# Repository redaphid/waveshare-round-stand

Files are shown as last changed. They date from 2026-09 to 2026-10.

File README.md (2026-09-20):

# Waveshare round-board desk stands

Minimal angled stands for Waveshare's round ESP32-S3 display boards. One design,
three sizes: a tapered wedge with a groove angled 20° back from vertical, and a
cable notch cut straight through the middle so a USB-C lead runs *through* the
stand rather than over it. The board drops in rim-first — nothing clips, nothing
flexes, no fasteners.

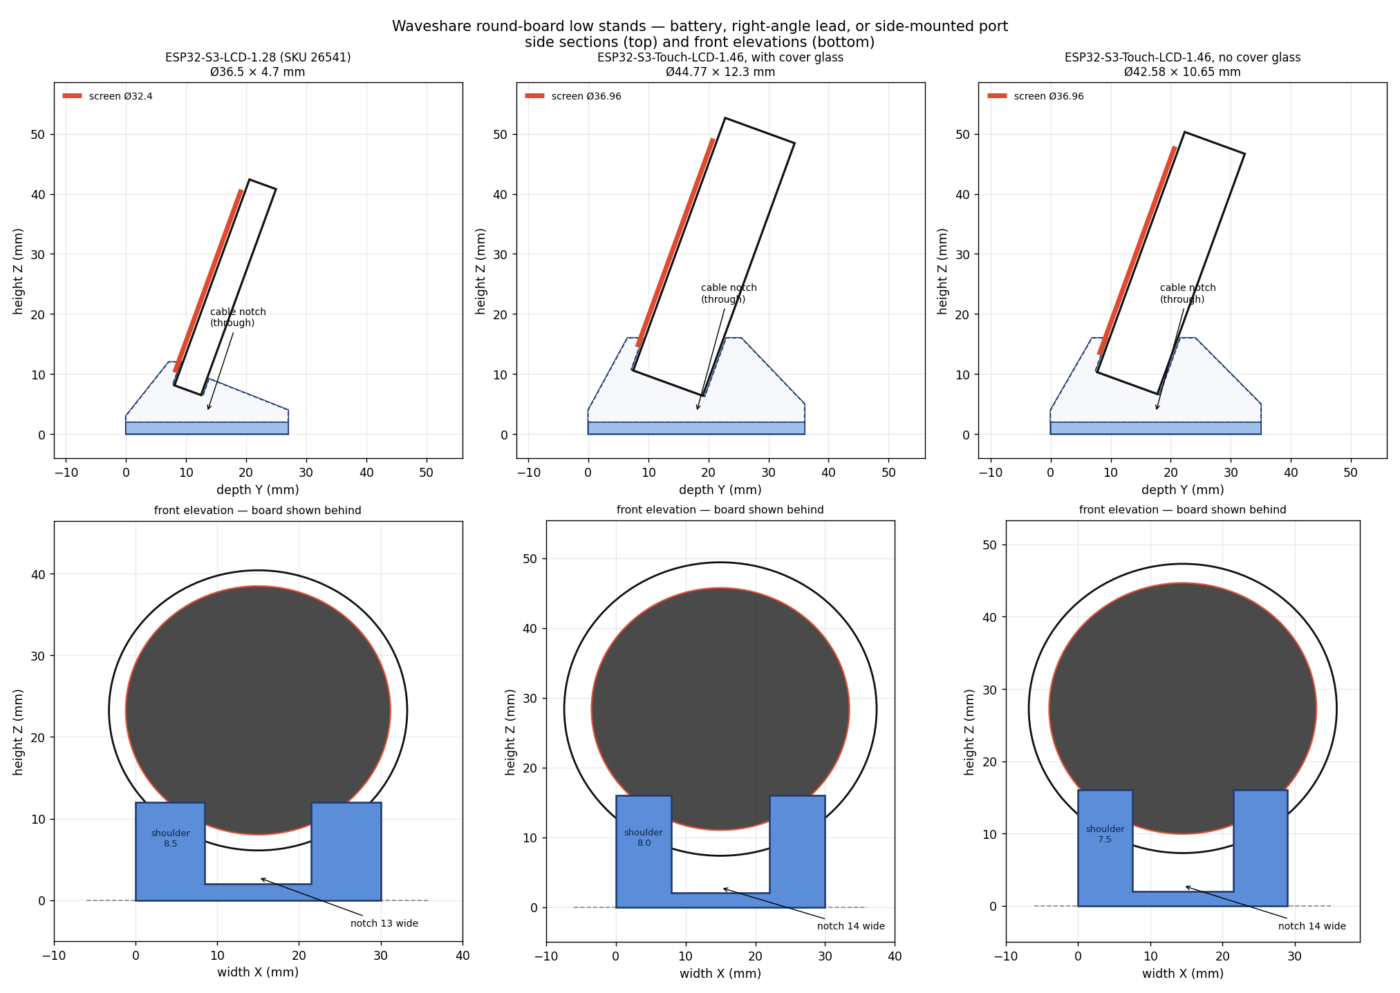
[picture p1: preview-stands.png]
low stands


| board | stand | groove | notch | screen top | material |
|---|---|---|---|---|---|
| ESP32-S3-LCD-1.28 (SKU 26541) | [`stl/small/Stand.stl`](stl/small/Stand.stl) | 5.4 × 5 mm (rear wall 3 mm) | 13 mm | 41.6 mm | 4.6 g |
| ESP32-S3-Touch-LCD-1.46, cover glass | [`stl/large/Stand - cover glass.stl`](<stl/large/Stand - cover glass.stl>) | 13.1 × 8 mm | 14 mm | 50.6 mm | 8.9 g |
| ESP32-S3-Touch-LCD-1.46, bare | [`stl/large/Stand - no cover glass.stl`](<stl/large/Stand - no cover glass.stl>) | 11.5 × 8 mm | 14 mm | 48.5 mm | 8.2 g |

### Docks — for a straight USB-C cable in the bottom port

The low stands leave ~5 mm under the board rim. A straight USB-C plug body is
~20–25 mm, so with the 1.46's bottom port in use the board can't seat — it ends
up lying across the stand. The docks lift the board so the plug hangs straight
down through the notch and the cable turns out the back at desk level.

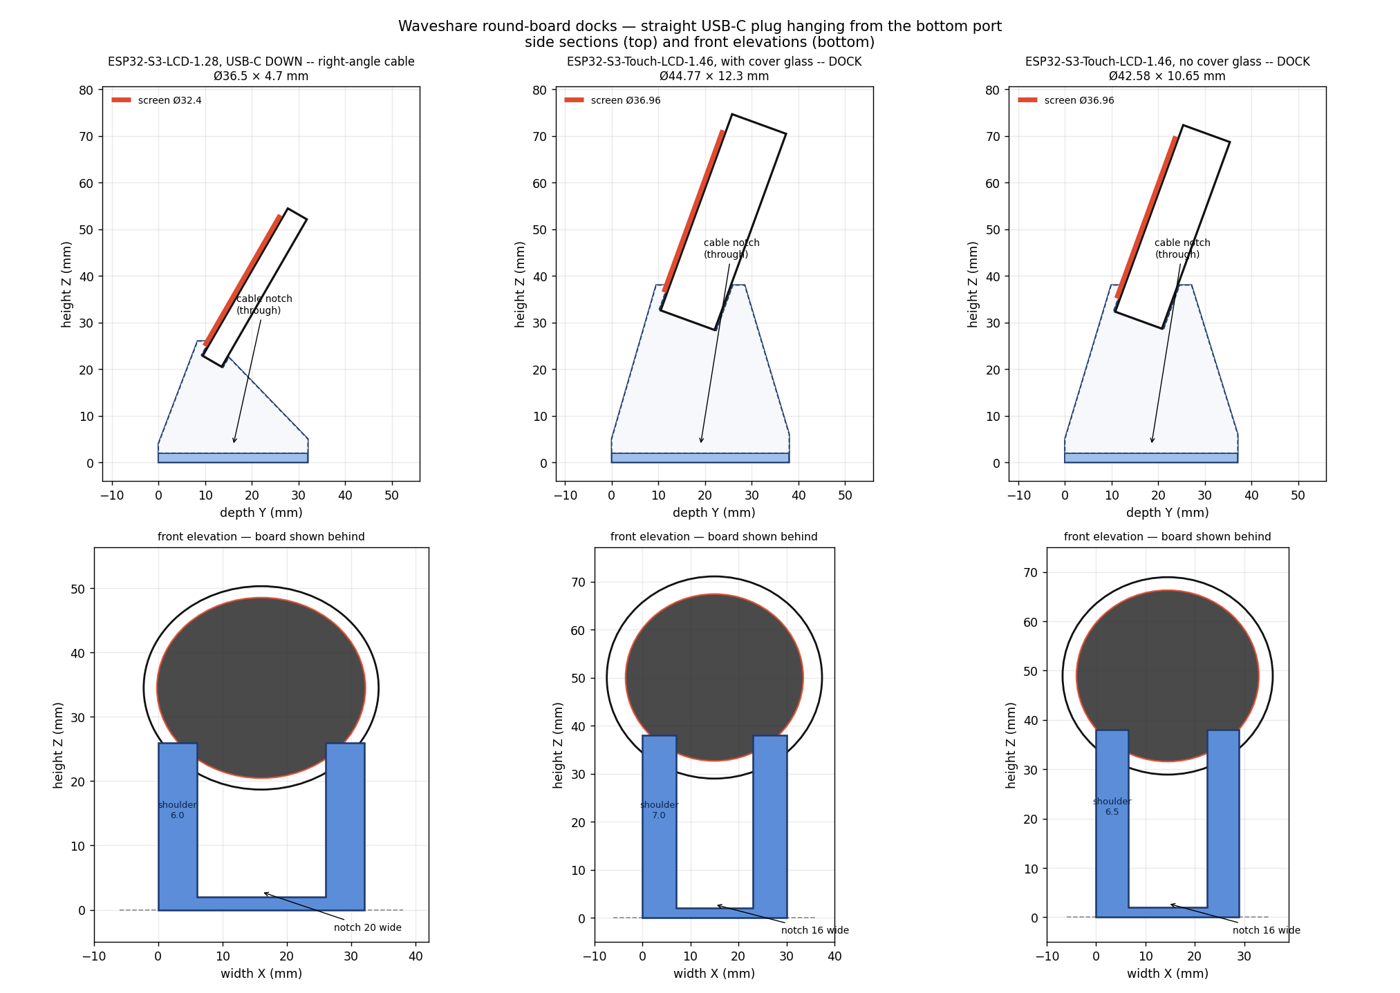
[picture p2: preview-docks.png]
docks


| board | dock | clear under rim | screen top | material |
|---|---|---|---|---|
| ESP32-S3-Touch-LCD-1.46, cover glass | `large/Dock for straight cable - cover glass.stl` | **27.0 mm** | 72.6 mm | 19.8 g |
| ESP32-S3-Touch-LCD-1.46, bare | `large/Dock for straight cable - no cover glass.stl` | **26.9 mm** | 70.5 mm | 17.9 g |
| ESP32-S3-LCD-1.28, **USB-C down** | `small/Dock for right-angle cable - USB-C down.stl` | **14.7 mm** | 51.3 mm | 9.4 g |

The 1.28 one is for an **L-shaped USB-C cable**: the badge goes in **turned
over**, tab down, so the port faces the desk. It leans back **30°** rather than
20 — that points the port down-and-forward, so the plug tucks into the notch
instead of needing headroom under the rim. The notch is **20 mm** to pass the
18.37 mm USB-C tab. The screen ends up upside down: **rotate it in firmware**.

Same groove, same notch (widened to 16 mm for plug bodies), ridge raised from
16 mm to 38 mm and the groove moved 3 mm back. Sized for a 24 mm plug body with
3 mm spare for the cable to turn. Because the board leans back, the plug leans
*forward* as it descends and lands about 6 mm in from the front edge; the notch
is open at both ends, so the cable runs out the front or 32 mm back along the
floor to exit behind. Twice the material of the low stand — the cost of holding
the board 27 mm off the desk.

Print flat on the base. No supports, no overhangs. Masses are PETG.

**1.28 with a button:** `stl/small/Stand - BOOT button.stl` adds a post behind the
badge's BOOT switch so pressing the screen clicks it (RESET twin too). Details
in [`PRINTING.md`](PRINTING.md#the-128-button-post-stands).

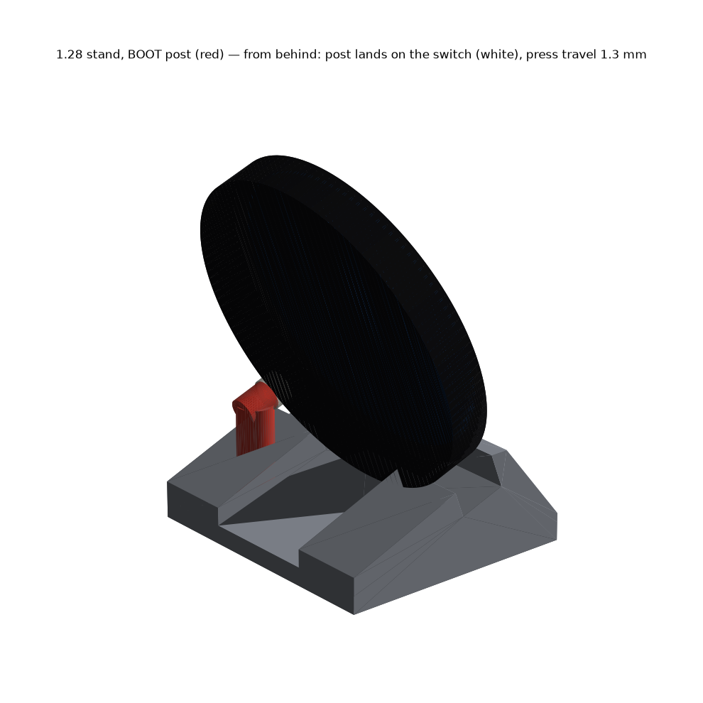
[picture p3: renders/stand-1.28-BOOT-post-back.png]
BOOT post


**Printable files live in [`stl/`](stl/).**

## The pod — where this is heading

The stands were the warm-up. The goal is an **instrument cluster clipped to the
side of a monitor** with the look of a 2G DSM A-pillar gauge pod: cups, trim
rings, gauges canted toward you. That lives in [`pod/`](pod/) — its own README,
STLs, and renders. The stands and docks above stay as they are.

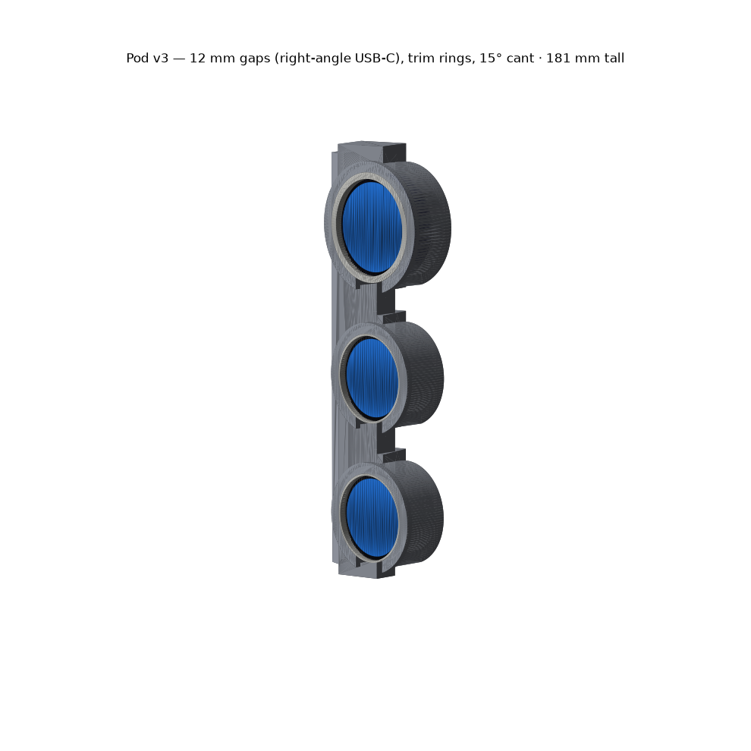
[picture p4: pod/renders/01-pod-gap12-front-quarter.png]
pod


## Start here

- **[`PRINTING.md`](PRINTING.md)** — which file to print, slicer presets, plate
  orientation, how to seat each board, what the notch does and doesn't do.
- **[`BOARDS.md`](BOARDS.md)** — verified dimensions and pin maps for both
  boards, how the two sizes actually compare, and how to tell the two 1.46
  variants apart.
- **[`reference/`](reference/)** — Waveshare's own outline and pinout drawings,
  with source URLs in [`SOURCES.md`](reference/SOURCES.md).

## Three things worth knowing

1. **The 1.46 ships in two cover-glass options and they are different parts** —
   Ø44.77 / 12.30 mm thick with glass, Ø42.58 / 10.65 mm without. The grooves
   differ by 1.65 mm. Check yours before printing; see `BOARDS.md`.
2. **On the low stands the notch is a cable route, not a plug socket.** It
   leaves 4.1–5.4 mm under the board rim — fine for a bare lead or a
   right-angle plug, not a straight plug in the bottom port. **For a straight
   plug, print the dock.** See `PRINTING.md`.
3. **The two boards are closer in size than they look.** The 1.46's PCB is only
   6.1 mm wider than the 1.28's. What differs enormously is thickness — 1.6 mm
   of bare PCB rim versus a 12.3 mm stack.

## Why these aren't from Printables

Nothing there targets these boards. Searches surface models for the
**ESP32-S3-Touch-LCD-1.28** (a different outline from the non-touch 1.28) or for
the bare 1.28-inch LCD module. So these are built from Waveshare's outline
drawings instead — neither product page states its dimensions in text, they
exist only inside a diagram image.

## Design

A straight groove holding a round board is the plate-stand trick: the disc
contacts the groove on two lines and cannot rock. It buys three things over a
cradle or a tripod — no supports needed, no thin snap features to fatigue, and
because the board is round you can rotate it to put the connectors where you
want them.

The solid is three slabs stacked across the width: full wedge, base slab, full
wedge. The two outer slabs carry the groove; the middle one is just the floor,
which is what makes the notch. Because the slabs share their lower boundary
exactly, the exposed face at each internal boundary is one simple polygon, so
the mesh comes out watertight without needing a general polygon boolean.
`check_stl.py` proves that rather than assuming it.

## Files

| file | what it is |
|---|---|
| `build_stands.py` | generates all five STLs from one parameter table; prints a geometry report and asserts the board fits the base, the centre of mass stays centred, the notch floor clears the groove floor, a cable actually fits under the rim, and — for docks — that a straight plug does |
| `build_stand_button.py [BOOT\|RESET]` | the 1.28 stand with a switch post; manifold3d, in the `~/.venvs/cad` venv |
| `build_all.sh` | everything below, plus a docs link-check; run before any commit |
| `check_stl.py <f.stl>` | verifies watertightness, outward normals, no degenerate facets; exits non-zero on a problem |
| `preview.py` → `preview-stands.png`, `preview-docks.png` | side sections and front elevations per family, board drawn in place |
| `stand.scad` | same model, parametric, for tweaking in OpenSCAD; set `variant` at the top |
| `flatten_presets.py` | resolves an ElegooSlicer preset's `inherits` chain into one flat preset — see the automation note in `PRINTING.md` |
| `pod/` | the gauge pod + adjustable monitor clip — see [`pod/README.md`](pod/README.md) |
| `archive/` | superseded files, kept rather than deleted; see `archive/NOTE.md` |

## For whoever works on this next

- **[`CLAUDE.md`](CLAUDE.md)** — the agent brief: what's verified, conventions, how to work here
- **[`docs/DESIGN.md`](docs/DESIGN.md)** — every design decision and what it replaced
- **[`docs/TOOLCHAIN.md`](docs/TOOLCHAIN.md)** — the two pipelines, venv setup, renderer limits, the slicer-CLI post-mortem
- **[`docs/PRINT-LOG.md`](docs/PRINT-LOG.md)** — what has actually been printed
- **`.claude/skills/`** — `rebuild-and-ship`, `add-board`, `measure-drawing`, `after-a-print`, `pod-iterate`
- **`./build_all.sh`** — rebuild, validate, render, link-check, in one go

## Regenerating

```
./build_all.sh
```

Or piecemeal:

```
python3 build_stands.py
for f in stl/*/*.stl; do python3 check_stl.py "$f"; done
python3 preview.py
```

Pure standard library for the STL generator and validator; matplotlib only for
the previews.

## Licence

MIT — see [`LICENSE`](LICENSE).

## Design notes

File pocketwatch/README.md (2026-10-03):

# Pocketwatch case (1.28 badge)

**Ø52.3 × 23.4 mm. Three parts. Sized for the Makerfocus 1000 mAh LiPo (7.4 × 22.28 × 42.65).**

| print | file | orientation | supports |
|---|---|---|---|
| **case** | `stl/pocketwatch/Pocketwatch - case.stl` | bezel face down, as exported | none |
| **plate** | `stl/pocketwatch/Pocketwatch - plate.stl` | flat back down, guides and post up, as exported | none |
| **lid** | `stl/pocketwatch/Pocketwatch - lid.stl` | flat, as exported | none |

## Assembly, in order

1. **Badge** into the case from the back, screen first, USB-C tab into the slot at 12 o'clock.
2. **Battery plug** through the square hole in the plate, then into the badge's JST.
3. **Plate** onto the step behind the badge, header sockets into the two guides. Press until it snaps.
4. **Battery** into the chamber, wire end toward 12 o'clock, wire laid in the channel on the plate.
5. **Lid** pressed in until it snaps.
6. Any straight USB-C cable into the recess at 12 o'clock. The cable is the chain.

**Press the screen to click BOOT.** The badge floats 0.7 mm. At rest the glass sits on the bezel lip. A press slides it 0.2 mm onto a post on the plate, then 0.25 more clicks BOOT. Every other part still has 0.25 mm of room at that point.

## Still guesses (the build prints these on every run)

| what | value | risk if wrong |
|---|---|---|
| switch position | (±11.1, −10.2) | post misses BOOT. The Ø3 post forgives ~±0.6 |
| switch height | housing 1.4, actuator 2.0 | no click, or a held-down button |
| JST position / size | (−7.6, 8.5), 8.4 × 4.0 | plate rubs the JST |

Measured and trusted: Ø35.31 envelope, 38.64 tip to far edge, tab 16.25 / 15.38, PCB back 4.53, header tops 8.15, JST top 7.64, port centre 5.0, headers 13.25 × 3.0 at a 30.0 outside span.

Headers' y position is not measured, and the design doesn't need it. The guides grip in x only and are open in y. The round board in the bore plus the tab in its slot locate y and rotation.

Rebuild: `~/.venvs/cad/bin/python pocketwatch/build_pocketwatch.py` from the repo root. Add `--no-render` for a fast check run.

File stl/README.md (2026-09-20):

# Printable files

One folder per badge, plus the pod.

| folder | badge |
|---|---|
| **`small/`** | the **1.28** (ESP32-S3-LCD-1.28, SKU 26541) — Ø36.5, non-touch |
| **`large/`** | the **1.46** (ESP32-S3-Touch-LCD-1.46). Yours is the **cover glass** one — every file says which it is for |
| **`pod/`** | the monitor pod, which holds both (one large on top, two small) |

Print everything flat as exported, no supports, unless the row says otherwise.
Slicer settings and seating: [`../PRINTING.md`](../PRINTING.md). Masses are PETG
at 1.27 g/cm³.

## `small/` — the 1.28

| file | what it is | material |
|---|---|---|
| `Stand.stl` | desk stand. 5.4 mm groove, sized with the fit gauge. USB-C tab at the top | 5.1 g |
| `Dock for right-angle cable - USB-C down.stl` | the badge **turned over**, USB-C facing **down**, for an L-shaped cable. Leans back 30°; the tab and the plug hang in the notch. Screen ends up upside down — **rotate it in firmware** | ~9.4 g |
| `Stand - BOOT button.stl` | the stand plus a post behind the badge: press the screen → clicks **BOOT** (GPIO0, the user button) | 4.7 g |
| `Stand - RESET button.stl` | same, clicks **RESET** | 4.7 g |
| `Pod cup test.stl` | one pod cup on a desk base — **print before the pod**. Exported face-up: print as is, then stand it on its two feet. Badge **USB-C tab down**, then press the trim ring in | ~16 g |
| `Trim ring - small.stl` | presses into a pod cup (or the cup test) to hold the badge in. The pod needs **2** | 0.4 g |
| `Slot fit gauge.stl` | eight slots, 3.0 → 6.5 mm. Slot N has N dots under it; slot 1 is at the chamfered end | ~6 g |

**Button stands:** seat the badge **USB-C at the top**; the post is behind the
lower-right (BOOT) or lower-left (RESET) as you look at it. See `PRINTING.md`.

**Pod cup test — what to report:** does the badge drop onto the ledge without
force, does the tab clear its notch, does the ring press in and hold. Loose or
tight: say which.

## `large/` — the 1.46

The two 1.46 versions are **not** interchangeable: 12.30 mm vs 10.65 mm thick,
so the grooves differ by 1.65 mm. Not sure which you have? See "telling them
apart" in [`../BOARDS.md`](../BOARDS.md).

| file | what it is | material |
|---|---|---|
| `Stand - cover glass.stl` | desk stand, **yours** | 8.9 g |
| `Dock for straight cable - cover glass.stl` | taller stand with 27 mm under the rim, for a **straight** USB-C plug in the bottom port | 19.8 g |
| `Trim ring - large.stl` | presses into the pod's top cup. The pod needs **1** | 1.4 g |
| `Stand - no cover glass.stl` | desk stand for the other version | 8.2 g |
| `Dock for straight cable - no cover glass.stl` | dock for the other version | 17.9 g |

**Stand or dock?** A straight USB-C cable in the bottom port needs the dock —
the stand leaves ~5 mm under the rim and a plug body is ~24 mm. Right-angle
cable, battery, or port turned sideways: the stand is fine and half the plastic.
The dock's notch is open both ends, so the cable can leave front or back.

## `pod/` — the monitor pod

| file | what it is | qty |
|---|---|---|
| `Pod - right-angle cables.stl` | the pod, 12 mm between gauges — for right-angle USB-C cables (yours). 181 mm tall | 1 |
| `Pod - straight cables.stl` | the pod with 26 mm gaps for straight plugs. 209 mm tall | instead of the above |
| `Clip - fixed jaw.stl` | clamps to the monitor edge (8–32 mm) | **2** |
| `Clip - slider.stl` | the clip's sliding jaw, locked with an M3 × 12 | **2** |

Plus from the other folders: `large/Trim ring - large.stl` ×1 and
`small/Trim ring - small.stl` ×2. Details in [`../pod/README.md`](../pod/README.md).

## Rebuilding

`./build_all.sh` from the repo root regenerates every file here.

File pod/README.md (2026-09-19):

# Gauge pod — pillar-pod look, clipped to a monitor edge

Three Waveshare round displays as an instrument cluster on the side of a
monitor. The reference is a 2G DSM A-pillar pod: cylindrical cups with trim
rings, gauges canted toward the driver, stacked on a spine. Adapted to a flat
monitor edge — straight spine, adjustable clamp — the shell shape that follows
a windshield pillar isn't reproduced.

pod, three-quarter

## What you print

**Test the cup first:** `../stl/small/Pod cup test.stl` + `../stl/small/Trim ring - small.stl` —
one 1.28 pod cup on a desk base, ~16 g vs ~40 g for the pod. It is the pod's
cup verbatim (`cup()` in `build_pod.py`), so if the badge seats and the ring
presses in there, the pod fits. Prints face-up, no supports; stand it on its
feet to use.

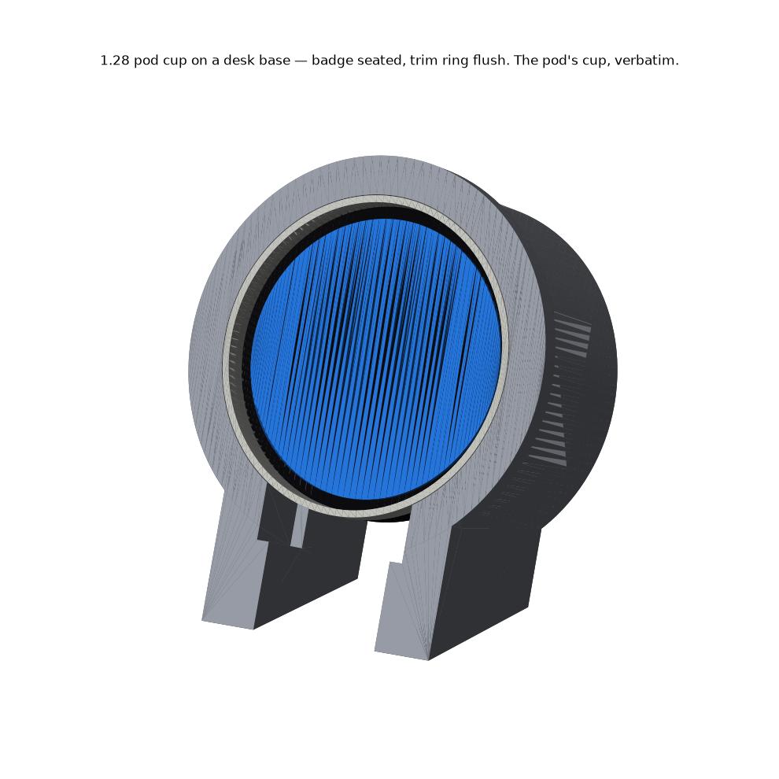
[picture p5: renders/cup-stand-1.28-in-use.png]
cup stand


**The 1.28s mount USB-C tab DOWN**, into the plug slot, same as the 1.46's port —
rotate the display 180° in firmware. The tab sticks out past the round edge, so
it can only go into the slot.

| part | qty | file | notes |
|---|---|---|---|
| pod | 1 | `../stl/pod/Pod - right-angle cables.stl` | for right-angle USB-C cables — the default. `../stl/pod/Pod - straight cables.stl` if you must use straight plugs |
| trim ring, 1.46 | 1 | `../stl/large/Trim ring - large.stl` | press fit, retains the gauge |
| trim ring, 1.28 | 2 | `../stl/small/Trim ring - small.stl` | |
| clip, fixed | **2** | `../stl/pod/Clip - fixed jaw.stl` | two clips on the full-height rail |
| clip, slider | **2** | `../stl/pod/Clip - slider.stl` | |
| hardware | 2 | M3 × 12 screw | lock, one per clip; self-taps into the tongue (Ø2.8 hole), or fit a heat-set insert |

Gauges, top to bottom: **1.46 cover glass, 1.28, 1.28** — the 60/52 mixed-stack look.

## Two gap sizes — the default is for right-angle cables

The 1.46's port is on its bottom edge and fires radially. Whatever hangs from it
lands in the gap below that cup, so the gap is sized by the plug.

| | `Pod - right-angle cables` (default) | `Pod - straight cables` |
|---|---|---|
| cable | **right-angle** plug, head ~12 × 6.5 × 9 mm | **straight** plug, ~24 mm body |
| rim-to-rim gap | 12 mm | 26 mm |
| height | **181 mm** | 209 mm |
| volume | 79 cm³ | 89 cm³ |

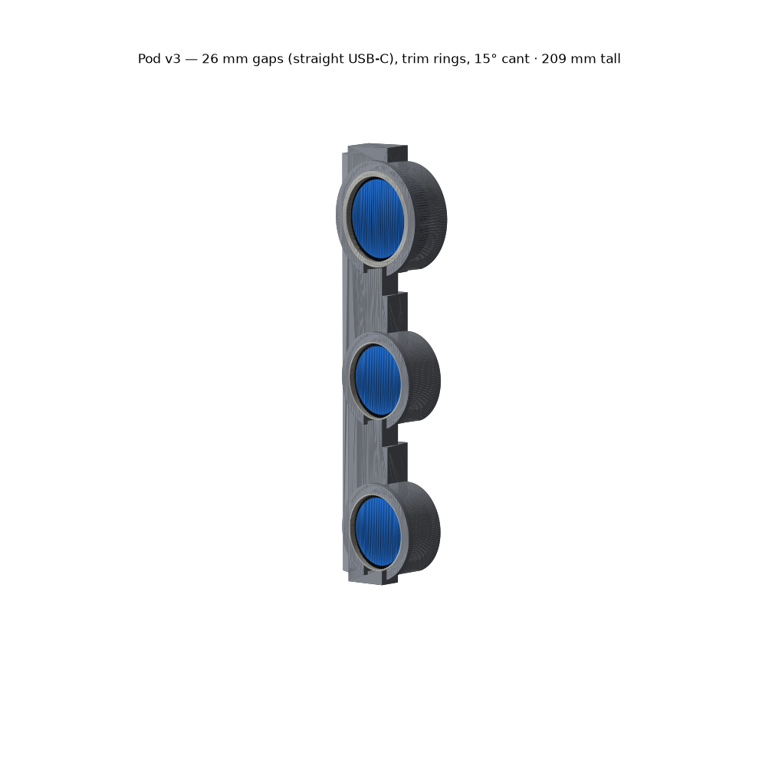
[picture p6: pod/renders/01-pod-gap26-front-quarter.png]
gap26 for comparison


Both fit the Centauri Carbon 2 bed (256 mm).

## How the gauges are held

Each cup is a tube with a **shoulder** behind the gauge and a **rear bore** the
back of the board passes through. A **trim ring** presses into the pocket in
front of the gauge, flush with the cup face — it's what stops the gauge falling
out forward, and it hides the PCB edge like a bezel.

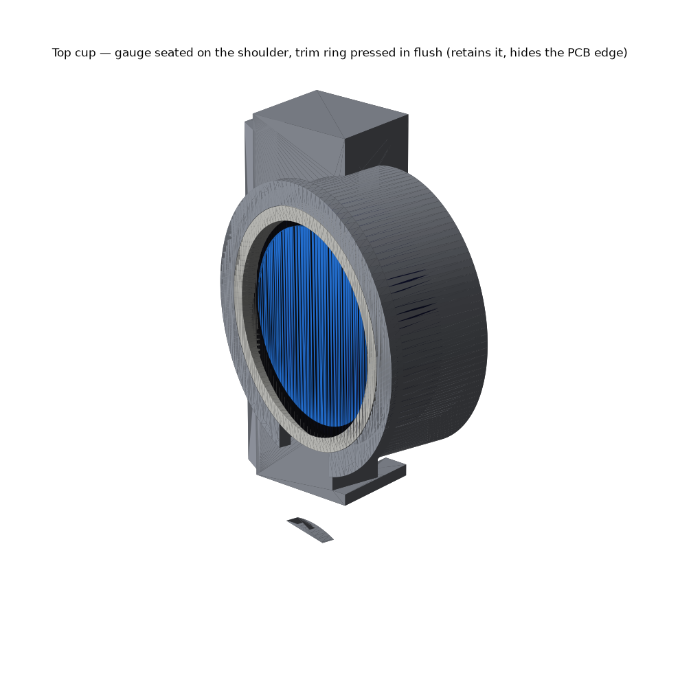
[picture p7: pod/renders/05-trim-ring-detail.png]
trim ring detail


- **1.46** — its cover glass overhangs the PCB by 1.1 mm all round. The shoulder
  grips *that*, and the bore is snug on the Ø42.58 PCB, so the whole 12 mm stack
  and its three brass standoffs pass straight through. The ring covers the glass
  edge out to Ø40.
- **1.28** — the shoulder grips the bare PCB rim; the bore (Ø33) clears its
  BOOT/RESET buttons and lets the header pins protrude into the spine.

Rings are 0.1 mm oversize. If one won't press in, sand; if loose, a dot of CA.

## Wiring

Each cup has a **16 mm drop slot** at its bottom for the right-angle plug head.
Right-angle USB-C cables come in two flavours — cable exiting **sideways**
(along the plug's wide axis) or **backward** (along its narrow axis) — and the
pod accepts either: a **pass-through** at each drop slot leads into the
**wiring channel down the back of the spine**, so the lead ducks in whichever
way it leaves the plug. Orient a backward-exit plug so the cable heads toward
the monitor, not toward you. The channel is open to the rear, hidden from you,
and exits at the bottom.

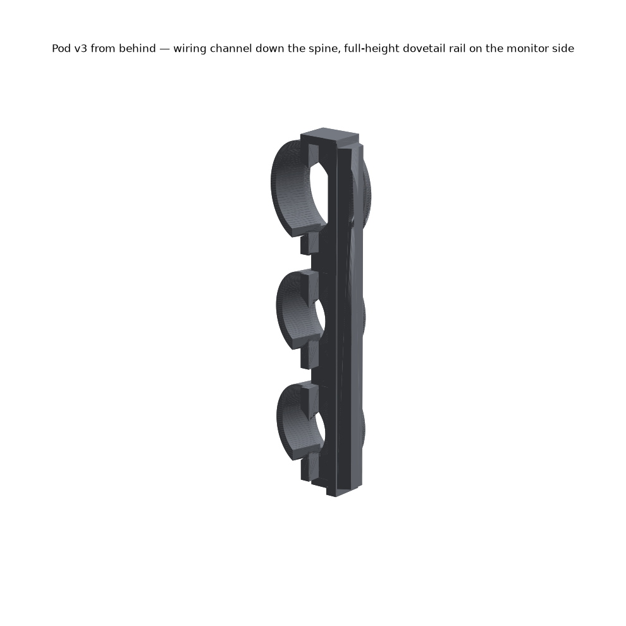
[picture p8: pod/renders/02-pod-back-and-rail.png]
back


## The clip — adjustable, 8–32 mm edges

A C-clamp: fixed front jaw (6 mm lip onto the bezel), spine, and a **sliding
rear jaw on a tongue**. Set it to your edge, drop an M3 through the slot in the
top into the tongue, tighten — the screw head bears on the spine and lifts the
tongue against the channel roof. Dovetail socket on the outer face carries the
pod; the pod's rail is full height, so **two clips** go anywhere along it and
the pod slides to the height you want.

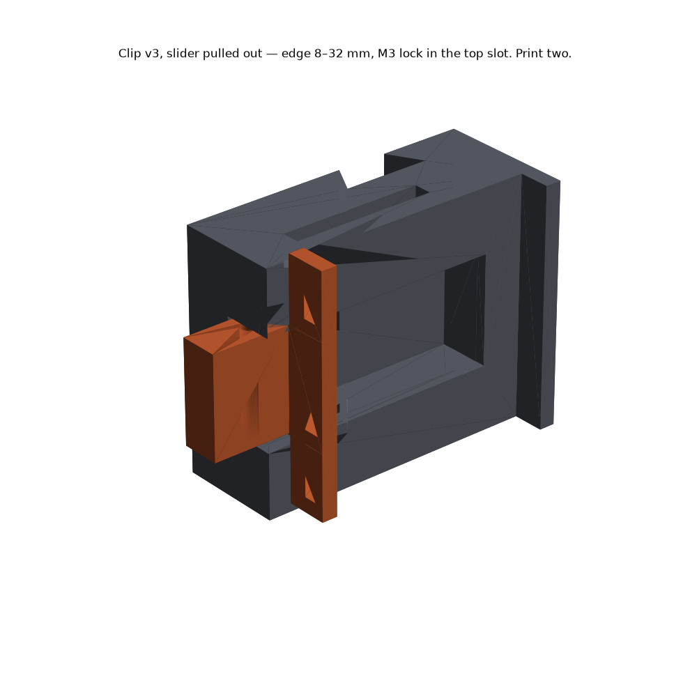
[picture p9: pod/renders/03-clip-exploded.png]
clip

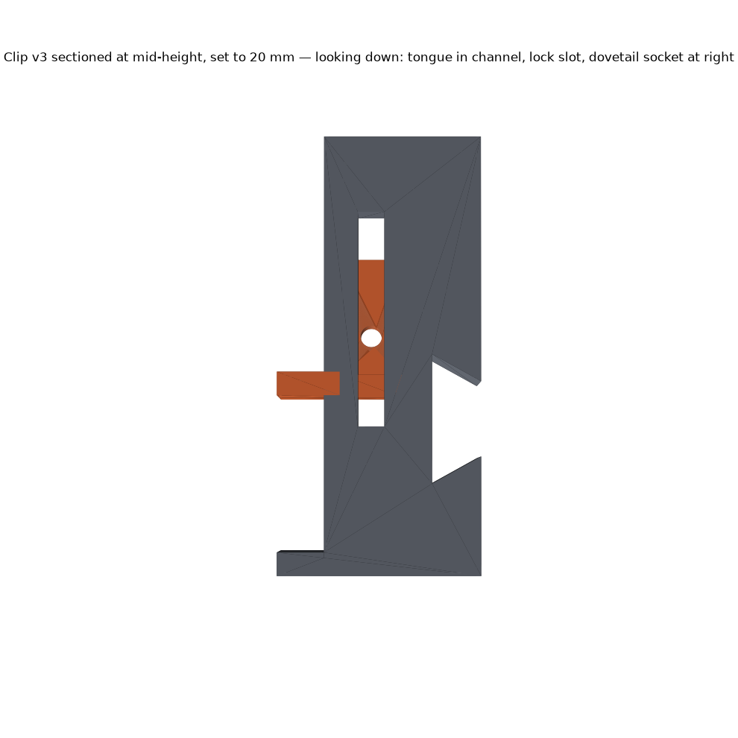
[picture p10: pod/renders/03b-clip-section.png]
clip section

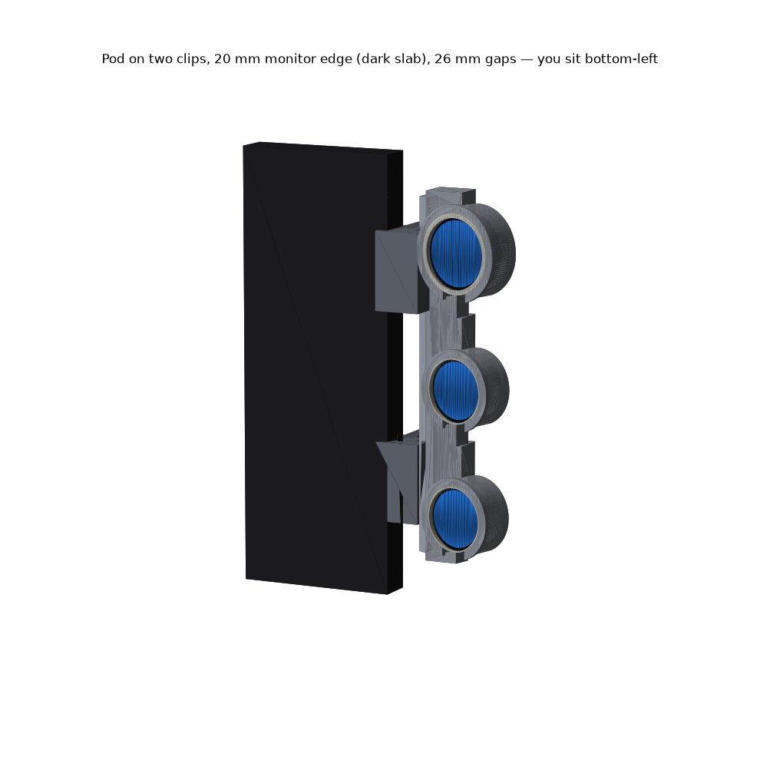
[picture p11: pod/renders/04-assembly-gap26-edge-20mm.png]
assembled, 20 mm edge


Renders also exist for 10 mm and 30 mm edges (`renders/04-assembly-*`).

## Printing

- **Pod: lying on its back** (spine's rear face on the bed). Cups become
  vertical cylinders — no supports. The wiring channel becomes a 12 mm bridge on
  the bed side; PETG handles it. The dovetail flanks are 60°, self-supporting.
- **Clips: fixed part on its outer (+X) face**, slider on its side.
- **Rings: flat.**
- Same PETG / 0.6 nozzle / 0.3 mm layer as the stands. Pod at 15 % infill is
  ~35–40 g printed, not the solid-volume figure above.

## Geometry notes

- Cups are canted **15°** about vertical toward you (the pod is drawn for the
  monitor's **right** edge; mirror for the left).
- Cup faces sit **6 mm proud of the screen plane** when mounted.
- Everything is generated by `build_pod.py` (manifold3d + trimesh, in the
  `~/.venvs/cad` venv). `render.py` does the pictures headlessly. Change a
  number, re-run: `~/.venvs/cad/bin/python build_pod.py` (gap12) and `… 26`.

## Still open

- Nothing printed yet. The ring press fit and the clip's tongue clearance are
  the two numbers most likely to need a tweak after the first print.
- The 12 mm gap assumes a right-angle head no deeper than ~9 mm radially. If
  yours is chunkier, `GAP` in `build_pod.py` is the one number to raise.
- No fillets where the cups meet the spine — manifold3d has no fillet op. It
  prints fine; it just looks crisper than a moulded pod.

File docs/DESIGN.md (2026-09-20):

# Design decisions

Chronological. Each entry: what was decided, what it replaced, why. When a
decision gets reversed, add a new entry — don't edit the old one.

## Stands

**Slot-wedge, not a cradle or tripod** (09-17). A straight groove holding a round
board contacts it on two lines and cannot rock; prints flat with no supports;
no snap features to fatigue; the round board rotates freely to put connectors
where you want. Replaced the "tripod" idea from the first brief.

**Prism construction** (09-17). One 2D side profile extruded across → trivially
watertight, every dimension is a number in a table. Pure standard library.
Limitation: nothing that varies along the extrusion. Worked around once (the
notch, as three slabs sharing a lower boundary); anything more → manifold3d.

**Groove grips the bare PCB rim** (09-17). The 1.28's 1.6 mm figure is the rim,
not the assembled board. Components are inboard; only the rim enters the groove.

**Two 1.46 variants, not one** (09-17). Waveshare sells the 1.46 with or without
cover glass: Ø44.77/12.30 vs Ø42.58/10.65. Grooves differ by 1.65 mm. Built both
rather than ask which he had; documented how to tell by eye. (He has cover glass
— confirmed from a photo 09-17.)

**Cable notch through the ridge** (09-17). Aaron asked for "notches to run USB-C
cables through". Centre slab is just the base floor; the two shoulders hold the
board. Also shed ~⅓ of the material. Then re-tuned so a cable actually fits under
the rim (4.1–5.4 mm) — the first cut left 2.4 mm.

**Front-elevation preview draws an ellipse** (09-17). A leaning disc projects
foreshortened; the first render drew a circle dipping below the desk. Preview
bugs are documentation bugs.

**Docks** (09-18). He printed the low stand, plugged in his straight cable,
photographed the board lying across it. A straight plug needs ~24 mm below the
rim; there were 5. Lifting the board is the only fix: ridge 16 → 38, notch
widened to 16, groove moved back 3 mm so the plug tip lands inside the base.
Low stands kept for battery / right-angle / side-port use.

**Header pins constrain seating** (09-18). Photo showed a 2×10 header fitted,
pins out the back. On the low stand the 20–50° band either side of bottom is a
hard clash; the dock's steep rear ramp clears everything. Natural orientation
(USB-C down) is safe on both.

## Button post

**Pad on a column, not a post along the board's normal** (09-18). At 20° lean the
normal is 20° below horizontal; a post along it exits the stand out the back
without touching it. Assert on buried length caught it.

**BOOT by default** (09-18). GPIO0 is what firmware reads as a user button;
RESET reboots. RESET twin generated anyway.

**Mechanics** (09-18). Badge leans on the groove's rear lip (5 mm up); switch is
7.7 mm up; a push at the top of the screen is levered ~11× onto the switch. Its
own weight → ~30 gf on the pad, under the ~160 gf a tactile switch needs.

**Switch positions measured from the drawing** (09-18). Disc fitted to R 18.25,
caps found by colour: BOOT back (−9.0, −8.3), RESET (+9.7, −8.3). Overlay saved
so the fit can be checked by eye. Ø3.2 pad forgives ±1 mm.

**1.28 groove 2.4 → 2.7** (09-18). First button-post print: the badge's groove
was slightly too small. Fit 0.8 → 1.1; shared with the plain 1.28 stand.

**…which was the wrong fix** (09-18). His photo shows the 1.28 in a case — the
rim is several mm thick, not 1.6. Fit gauge printed to measure it; the groove
gets the gauge's number, not another guess.

**1.28 groove 5.0, thick 4.7** (09-18). Gauge photo: no case — the display
module itself reaches the rim. Drops into the 5.0 slot. `thick` 4.7 moves the
button post back to meet the switch. Pod 1.28 cups: `seat_t` 1.6 → 4.7, so the
pocket is 7.7 deep (seat + ring) and the trim ring lands on the display module,
not 3 mm proud of it.

**1.28 groove 5.0 → 5.4; button pad placed from the front wall** (09-20). The
5.0 stand printed "just barely too narrow": the gauge's slots are vertical, the
stand's groove leans 20°, and leaned walls print as 0.3 mm stair-steps that each
reach ~0.1 into the slot. His worry — a wider slot lets the badge sink away from
the post — was wrong about height (the groove *floor* sets that) but found a real
hole: the pad was placed from the groove centre with nothing checking the badge
could rock far enough to click. At 5.0 it could not: **0.10 mm** of press travel
before the badge bottomed out on the front wall; a tact switch needs ~0.25. A
wider groove *helps*. Replaced: pad at `T/2 + CAP_H + REST_CLR` from the centre
→ `REST_CLR` clear of the cap with the badge upright against the front wall.
Now **0.8 mm** of travel, ≥0.7 for any rim 4.5–4.9 thick, and
`build_stand_button.py` asserts ≥ 2× switch travel.

**USB-C down, for the right-angle cable** (09-20). He bought an L-shaped USB-C
lead and wanted the port facing down. Turning the badge over moves three things
at once, so this is a new part rather than a parameter:

- the **USB-C tab sticks 2.85 mm past the disc** (BOARDS.md), so tab-down the
  tab *and* the plug hang into the cable notch — the notch has to pass an
  **18.37 mm tab**, not a cable. 13 → **20 mm**, shoulders 6 mm each.
- **BOOT/RESET go to the top**, out of the groove entirely — the fault that
  broke the 20° stand cannot happen here.
- the **headers and the battery JST come down** toward the groove instead.
  `rear_lip` 2.5 keeps the rear wall below both.

**Leaning it 30° rather than 20° is what makes it work**, and it was his hunch.
The port then fires down-*and-forward*, so the plug tucks into the notch instead
of demanding headroom under the rim; the dock is 26 mm at the ridge instead of
the ~30 a 20° version would need. Push the lean much further and the plug walks
out of the front of the base — at 30° it ends 2.6 mm inside it.

Checked as **solids, not arithmetic**: `build_stand_usbdown.py` builds the
badge, tab, plug, both headers, the JST and both switches and asserts each has
**zero** overlap with the stand. That is what caught the plug's corner grazing
the notch floor, which the centreline arithmetic had passed.

Not verified against his actual cable: `plug_len` 12 mm is a generous guess for
a right-angle plug. It is one number in `BOARDS["1.28-usbdown"]`.

**The switches are at the rim, so the groove's rear wall had to go** (09-20).
The 5.4 stand seated the badge but BOOT would not click: the white switch
housing was hard against the groove's rear wall. Measured the switches off
Aaron's own back-view photo instead of the drawing — **r 15.5, only 2.7 mm in
from the rim**, where the drawing put them at r 12.2. At that radius the housing
sits *below* the rear lip, and since it stands ~1.7 mm off the PCB the badge is
~6.4 mm thick there: it cannot enter a 5.4 mm groove **at any depth**. The badge
was propped proud and pushed forward, which is why the post could not reach.

Fix: `rear_lip`, a new optional parameter that stops the groove's **rear** wall
short of the ridge (1.28: 3.0 mm, where the full wall would be 5.98). The front
wall is untouched, so the badge is still held 5 mm deep. This does two jobs —
the housings clear by 1.8 mm, and the **pivot drops**, which is what gives a
press travel at all: 0.02 mm at the old full-height lip, **1.33 mm** now, against
the ~0.25 mm a tact switch needs. Lever to the top of the screen ≈ 9×.

Why not just a shallower groove: the housing reaches down to 4.8 mm up the
board, so clearing it with depth alone means a ~2 mm groove — too little to hold
the badge. Lowering only the rear wall keeps the depth and buys the travel.

`width` 26 → 30 came with it: the post sits at |x| 11.45 and needed shoulder to
root in. `build_stand_button.py` now asserts both things that were silently
false before — that the housing clears the rear lip, and that a press has ≥ 2×
the switch's travel.

**Cup stand, and what it caught before printing** (09-18). A test of the pod's
cup at ~16 g: `cup()` pulled out of `pod()` (pod STL byte-identical after the
refactor), put on a 20° desk base, exported face-up. Rendering it against the
drawing showed two things that would have made the 1.28 un-seatable in the pod:
the **USB-C tab reaches r 21.1**, outside the Ø37.2 pocket — now notched, tab
down into the plug slot; and the **H1/H2 headers reach r ~17** against a 16.5
bore — now relieved through the shoulder, 10 mm deep. Both live in `cup()`, so
the pod has them too.

## Pod

**Cups on a spine, not a box with holes** (09-18, v2). v1 was a rectangular block
with cylinders subtracted. Zero pillar-pod character. Real pods: the cylinders
are the form, the body joins them.

**Spine on the monitor side, cups cantilevered outboard** (v2). The rail on the
spine's monitor-facing side mates the clip's outer face, so the pod faces you.
Wiring channel down the *back* of the spine. (v1 had the rail on the back and
the channel on the side — the pod would have faced away from the user.)

**Trim rings** (v3). Nothing in v2 stopped a gauge falling forward. Press-fit
ring in front of each gauge, flush with the cup face; also hides the PCB edge.
Standard gauge-pod construction.

**1.46 shoulder grips the glass** (v3). Its brass standoffs would foul a normal
shoulder. The glass overhangs the PCB by 1.1 mm; the shoulder grips that and a
snug Ø42.58+0.5 bore passes the whole stack. The 1.28's bore is Ø33 — past its
buttons, inside the PCB rim.

**Two clips, full-height rail** (v3). A 45 mm clip on a 209 mm cantilever would
rock. Two clips anywhere on the rail; pod slides to height.

**Adjustable clip, 8–32 mm** (v1→). Fixed front jaw with 6 mm bezel lip, sliding
rear jaw on a tongue, M3 lock through a slot in the *top* (the outer face is
taken by the dovetail socket). Spine 20 mm so tongue channel and socket root
have 4 mm between them (was 2 at 18).

**gap12 default** (09-18). Right-angle cables bought. 181 mm vs 209. Drop slot
widened 11 → 16 for the head; a pass-through from each drop slot into the wiring
channel so the lead tucks in whichever way the plug exits. gap26 kept.

**No fillets** (standing). manifold3d has no fillet op. Prints fine; looks
crisper than a moulded pod. Revisit only if he asks.

## Not done / rejected

- **Headless slicing.** ElegooSlicer CLI: `type`/`from` fields and `inherits`
  resolution solved (`flatten_presets.py`), then exit 239 with no diagnostic.
  Dropped on Aaron's say-so; he slices in the GUI.
- **M2 screw retention for the 1.46** in the pod. Would be more robust than the
  ring; needs the three hole coordinates, which the drawing gives only
  partially (23.54 lower spacing). Trim rings chosen instead.
- **Mirroring the pillar's curve.** Explicitly ruled out: "adapted to a modern
  monitor, we don't have to mirror the angle of the pillar".

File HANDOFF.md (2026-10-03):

# Handoff (2026-10-03, paused for session limits)

**Read this first, then `CLAUDE.md`.** Repo: WSL `survivor` `~/Projects/waveshare-round-stand`, public on GitHub as `redaphid/waveshare-round-stand`. `D:\Projects\waveshare-round-stand` is a non-git mirror Aaron slices from.

## Where things stand

| branch | head | state |
|---|---|---|
| `main` | 02388f7 | stands, docks, pod. **No pocketwatch yet.** |
| `pocketwatch` | this commit | **pocketwatch v2, ready to test-print.** Not merged to main. |
| `coworker-kit` | 051ad54 | **WIP, unreviewed.** Pocketwatch CLI only. Worktree at `~/Projects/waveshare-round-stand-kit`. |
| `pocketwatch-v2` | 373f536 | stale v1. Worktree `~/Projects/waveshare-round-stand-v2`. Safe to remove. |

## Pocketwatch v2 (the thing Aaron is printing)

- `pocketwatch/build_pocketwatch.py` builds three parts: **case**, **plate**, **lid**. Ø52.3 × 23.4 mm, sized for his Makerfocus 1000 mAh LiPo (7.4 × 22.28 × 42.65).
- STLs are in `stl/pocketwatch/`, also copied to the D: mirror. Print order: **plate first** (smallest, tests the riskiest guesses), then case and lid. All three print with no supports, as exported.
- Every check passes: solid-overlap at rest and pressed, BOOT is the only contact when pressed, guide engagement, lip clears the display, snaps interfere, minimum walls, watertight, and **no unsupported overhang beyond a 4 mm bridge**. The overhang check was added after Aaron's slicer caught a floating 14 mm span over the USB-C recess. It's now a 45° arch.
- Design and assembly: `pocketwatch/README.md`.

**Measured** (Aaron's calipers, Miro board `uXjVHk7UnLA=`, photos in `reference/pictures/`): Ø35.31 envelope, 38.64 tab tip to far edge, tab 16.25 / 15.38, PCB back 4.53, header tops 8.15, JST top 7.64, port centre 5.0, headers 13.25 × 3.0 at a **30.0** outside span.

**Still guesses** (printed at the top of every build): switch position (±11.1, −10.2), switch height (housing 1.4, actuator 2.0), JST position and size. If the test print doesn't click, it's one of these.

## Requirements Aaron gave (don't lose these)

- Pocketwatch look. The USB-C plug at 12 o'clock is the crown, and **any straight cable** is the chain. No right-angle-plug sizing needed.
- **The back engages the headers** to seal it in, **and an arm clicks BOOT when the screen is pressed.** So the guides grip in x only, are open in y and free in z. The badge floats 0.7 mm, and the back is fixed to the case, not the board.
- Don't make him measure things a design can avoid. He has little time.

## Next: coworker kit (Aaron's latest ask)

Coworkers with printers and the same 1.28 board should be able to make their own cases (other batteries) and stands. Full spec is the brief that started `coworker-kit`:

1. `requirements.txt` + `setup.sh` (repo-local `.venv`; fall back to `~/.venvs/cad`).
2. Pocketwatch CLI: `--battery TxWxL` or a code like `402030`, `--set NAME=VALUE`, `--name NAME` → `stl/pocketwatch/NAME/`. **Started in 051ad54, unreviewed.** Test across 7.4x22.28x42.65, 401730, 402030, 503035, and a huge one.
3. `build_all.sh` builds the pocketwatch and link-checks the new docs.
4. `START-HERE.md` for coworkers. README pointer. A "your own battery" section in the pocketwatch README. In `CLAUDE.md`, move owner-only facts under an "Owner's workflow" heading.
5. Skills: `make-pocketwatch`, `make-stand`, `tune-fit`. Mark `rebuild-and-ship` and `after-a-print` owner-only.
6. Verify with a fresh clone, then `./setup.sh`, then a custom battery build. Then merge `pocketwatch` (+ kit) to `main`.

**Known inconsistency:** desk stands use Waveshare's drawing Ø36.5, the pocketwatch uses the measured Ø35.31. The stands are print-proven, so leave their geometry and just document it.

## Open loose ends

- No print result yet for pocketwatch v2. Log it in `docs/PRINT-LOG.md` when it comes.
- The USB-C-down dock (`stl/small/Dock for right-angle cable - USB-C down.stl`) missed on print. Its model used drawing numbers that the calipers later corrected. It's superseded by the pocketwatch direction, so it hasn't been fixed.

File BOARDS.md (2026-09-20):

# Board reference

Everything here was read off the outline drawings in `reference/`. Waveshare
states none of it in page text — the product pages say only "tiny size" and
point at an image.

## ESP32-S3-LCD-1.28 (SKU 26541)

Non-touch, GC9A01 driver. This is the board from Waveshare order
`260713-003325-E0` (12 Jul 2026, 10 pcs).

| feature | value |
|---|---|
| PCB outline | **round, R 18.25 → Ø 36.5 mm** |
| PCB thickness | 1.6 mm (standard 2-layer; not stated on the drawing) |
| **thickness at the rim** | **~4.7 mm** — the display module on the front reaches almost to the PCB edge. Measured with the fit gauge 09-18: drops into the 5.0 slot. |
| USB-C tab | **sticks out past the disc**: 18.37 mm wide at its root, reaches r ≈ 21.1 (vs R 18.25) — measured off the drawing, 13.3 px/mm, 09-18. Irrelevant to the stands (it is at the top); in the pod it goes down into the plug slot. |
| USB-C | 12.81 mm wide, sits on the tab, **inserts sideways/upward** |
| active display | **Ø 32.4 mm**, 240 × 240 |
| headers | H1 + H2, 1.27 mm pitch, 20 pins each, ~27.00 mm outer span |
| buttons | BOOT and RESET, lower left and lower right |
| battery | MX1.25 2-pin |

### Pin map

`H1` (left, pins 1–20) and `H2` (right, pins 1–20), viewed from the front:

| H1 odd | | | H1 even | | H2 odd | | | H2 even |
|---|---|---|---|---|---|---|---|---|
| GP36 | 1 | 2 | GP46 | | GP5 | 1 | 2 | GP13 |
| GP35 | 3 | 4 | GP45 | | GP4 | 3 | 4 | GP12 |
| GP34 | 5 | 6 | GP42 | | GP3 | 5 | 6 | GP11 |
| GP33 | 7 | 8 | GP41 | | GP2 | 7 | 8 | GP10 |
| GP21 | 9 | 10 | GP40 | | GP1 | 9 | 10 | GP9 |
| GP18 | 11 | 12 | GP39 | | GP0 | 11 | 12 | GP8 |
| GP17 | 13 | 14 | GP38 | | RUN | 13 | 14 | GP7 |
| GP16 | 15 | 16 | GP37 | | BOOT | 15 | 16 | GP6 |
| GP15 | 17 | 18 | VSYS | | ADC_AVDD | 17 | 18 | VSYS |
| GP14 | 19 | 20 | GND | | GND | 19 | 20 | GND |

Fixed-function pins:

| pin | signal | |
|---|---|---|
| GP1 | BAT_ADC | battery voltage, divided by 2 |
| GP6 / GP7 | IMU_SDA / IMU_SCL | I²C to the QMI8658C |
| GP8 | LCD_DC | command/data select |
| GP9 | LCD_CS | chip select |
| GP10 | LCD_CLK | SPI clock |
| GP11 | LCD_DIN | SPI MOSI |
| GP12 | LCD_RST | reset |
| GP40 | LCD_BL | backlight |
| GP47 / GP48 | IMU_INT1 / IMU_INT2 | IMU interrupts |

## How the two compare

Worth stating plainly, because "1.28 vs 1.46" sounds like a bigger jump than it
is. Those numbers are screen diagonals in inches; the boards around them are
much closer in size than the thickness difference suggests.

| | 1.28 | 1.46 | delta | ratio |
|---|---|---|---|---|
| active screen | 32.40 | 36.96 | +4.56 mm | 1.14× |
| PCB diameter | 36.50 | 42.58 | **+6.08 mm** | 1.17× |
| outermost (1.46 = cover glass) | 36.50 | 44.77 | +8.27 mm | 1.23× |
| thickness at the rim | 1.60 | 12.30 | +10.70 mm | **7.69×** |

The screen ratio 36.96 / 32.40 = 1.141 matches the name ratio 1.46 / 1.28 =
1.141 exactly, which is a useful cross-check that both drawings were read right.

So the 1.46 is a **17 % wider PCB** — noticeable, not dramatic. The real
difference is depth. And note the 1.28's 1.6 mm is the *bare PCB* — **wrong for the groove**: the
display module sits on the rim too, ~4.7 mm total (09-18 fit gauge); its assembled height with headers and USB-C is far
more than that. The 1.46's 12.30 mm, by contrast, is the whole stack, because
its glass and PCB are laminated into one puck.

### Switch positions (measured)

**Measured off a photo of Aaron's own board** (09-20), not off the drawing. The
drawing-derived numbers were **3.3 mm too far in and 2.2 mm too high**, which is
what made the button stand fail: the switch housing landed below the groove's
rear lip and could not enter it. Overlay:
`reference/esp32-s3-lcd-1.28-switch-positions-photo.png`.

Scale from the PCB's widest row (36.50 mm — horizontal distances are not
foreshortened by the 20° lean); |x| from the switch-to-switch separation; height
from the board's half-width at the switches' own row. Accuracy ~±0.4 mm.

| switch | back view (+x right, +y up) | front view | r | in from the rim |
|---|---|---|---|---|
| **BOOT** (GPIO0) | (−11.45, −10.5) | (**+11.45**, −10.5) — lower **right** as you look at it | 15.5 | **2.7 mm** |
| **RESET** | (+11.45, −10.5) | (−11.45, −10.5) — lower **left** | 15.5 | **2.7 mm** |

They sit **close to the rim** — that is the fact that matters to anything
gripping the edge. The old drawing-fitted overlay
(`reference/esp32-s3-lcd-1.28-switch-positions.png`) is kept for comparison but
is **superseded**.

With the USB-C chord at the top. Cap ≈ Ø1.9, switch body ~3.5 mm square,
~2 mm tall off the PCB.

## ESP32-S3-Touch-LCD-1.46

Capacitive touch, 412 × 412, ESP32-S3R8. Adds a QMI8658 IMU, PCF85063 RTC, TF
slot, speaker and microphone.

**It ships in two cover-glass options, and they are different parts.** Check
yours before printing a stand — the groove differs by 1.65 mm.

| | with cover glass | without cover glass |
|---|---|---|
| front element | round glass disc, **Ø 44.77** | rounded-rect panel, **39.36 × 41.53** |
| widest part | the glass, Ø 44.77 | **the PCB**, Ø 42.58 |
| total stack | **12.30 mm** | **10.65 mm** |
| secondary thickness dim | 11.00 | 9.33 |
| active display | Ø 36.96 | Ø 36.96 |
| PCB | Ø 42.58 / 41.33 | Ø 42.58 / 41.33 |
| stand to print | `...-coverglass.stl` | `...-bare.stl` |

**Telling them apart:** the cover-glass version has a glossy black disc that
overhangs the PCB all the way round and hides the panel edge. The bare version
shows the panel's flex tail at the bottom and the PCB rim sticks out past the
panel on the left and right.

Common to both:

| feature | value |
|---|---|
| mounting | 3 × **M2** holes |
| header | 2×10, on the back; if populated the pins protrude rearward and constrain how you seat the board — see `PRINTING.md` |
| USB-C | bottom edge, **inserts downward** — see the orientation note in `PRINTING.md` |
| hole spacing | 23.54 mm between the two lower holes |
| other datums | 8.32, 10.41, 31.17, 32.70, 41.33, 42.58 |

### Pin map — single 20-pin header

| odd | | | even |
|---|---|---|---|
| GP13 | 1 | 2 | GP17 |
| GP12 | 3 | 4 | GP16 |
| RXD | 5 | 6 | GP14 |
| TXD | 7 | 8 | GP3 |
| GND | 9 | 10 | GP1 |
| 3V3 | 11 | 12 | GP0 |
| SDA | 13 | 14 | DP |
| SCL | 15 | 16 | DN |
| GND | 17 | 18 | GND |
| BAT | 19 | 20 | 5V |

`DP`/`DN` are the USB data pair; `SDA`/`SCL` are the external I²C.

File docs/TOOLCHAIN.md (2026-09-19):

# Toolchain

Two pipelines. Know which you're in before you type `python`.

## 1. Pure standard library — stands, docks, validator, previews

`build_stands.py`, `check_stl.py`, `preview.py`. **System `python3`** (3.14).
`preview.py` needs matplotlib, which the system python has. Nothing else.

- Geometry is one 2D profile per stand, extruded; the notch is three slabs
  sharing a lower boundary so each internal face is a simple polygon.
  Ear-clipping triangulation, binary STL out.
- `check_stl.py <f>`: every directed edge used exactly once and paired, signed
  volume positive (normals outward), no zero-area facets. Exits non-zero on a
  problem — chain it in scripts.
- Limit: anything that varies along the extrusion. Don't fight it; use pipeline 2.

## 2. manifold3d — pod, clip, rings, button post

`pod/build_pod.py`, `build_stand_button.py`, `pod/render.py`. **Venv python:**

```
~/.venvs/cad/bin/python pod/build_pod.py          # gap12 (default)
~/.venvs/cad/bin/python pod/build_pod.py 26       # straight-plug variant
~/.venvs/cad/bin/python build_stand_button.py BOOT
```

Rebuild the venv from scratch if it's gone:

```
python3 -m venv ~/.venvs/cad
~/.venvs/cad/bin/pip install manifold3d trimesh numpy matplotlib
```

Don't try `pip install --user` — PEP 668 blocks it on this box, and there's no
sudo. No OpenSCAD installed either (`stand.scad` is for Aaron's own machine).

- `manifold3d` does robust booleans (`+ - ^`), `hull`, extrude, rotate,
  translate. **No fillets.** Check `.genus()` and trimesh `is_watertight` after
  every union; a failed boolean is silent.
- `manifold3d` has no `__version__`. Cylinders build along +Z from z=0; rotate
  them into place. When the sign of a rotation matters, **check numerically**
  (see `along_perp()` in `build_stand_button.py`) rather than trusting it.
- `pod/render.py`: headless matplotlib, no GL. **All solids go into one
  depth-sorted `Poly3DCollection`** — per-solid collections draw in layers and
  hide interior parts (v1 bug). Painter's algorithm still gets interpenetrating
  meshes slightly wrong; that's cosmetic. Key light + sky term for shading.
- Sectioned views: subtract a box (`man - boxat(...)`) or intersect (`man ^ box`)
  and render the result. Cheap and very informative.

## Validating a build

`./build_all.sh` does all of this; by hand:

```
python3 build_stands.py && for f in stl/*/*.stl; do python3 check_stl.py "$f"; done
python3 preview.py
~/.venvs/cad/bin/python pod/build_pod.py && ~/.venvs/cad/bin/python pod/build_pod.py 26
~/.venvs/cad/bin/python build_stand_button.py BOOT && ... RESET
python3 - <<'PY'   # relative links + images resolve
...
PY
```

Then **open the renders**. A clean report is necessary, not sufficient.

## Measuring from a vendor drawing

Waveshare states dimensions only inside images. Procedure that worked twice
(`reference/esp32-s3-lcd-1.28-switch-positions.png` is the output):

1. `curl` the wiki page, `grep -oE '/w/upload/[^"]*\.(jpg|png)'`, pull the
   candidates, view them. The outline drawing is usually `…-003.jpg` or
   `…-introduction-04.jpg`. Save it under `reference/` and cite it in
   `reference/SOURCES.md`.
2. Read the dimensioned drawing directly (the Read tool shows images).
3. For features the drawing doesn't dimension: threshold the PCB colour to fit
   the disc, use one known dimension (R 18.25) for the px→mm scale, find the
   feature blobs by colour + size + radius band, `scipy.ndimage.label`. Save an
   overlay with the fit circle and a mm grid so the number can be checked by
   eye later. ±0.5 mm is realistic.

System python has numpy, scipy, PIL, matplotlib for this.

## Printer and slicer

- **Elegoo Centauri Carbon 2**, 0.6 nozzle, `10.0.4.1`. Reached through the
  `soul` MCP: `centauri__get_status`, `centauri__print_history`,
  `centauri__upload_file`, `centauri__start_print`. Errors like *":1883 (CC2/MQTT)
  is closed and :3030 (CC1/SDCP) did not answer"* mean it's powered off, not
  misconfigured — ask before assuming.
- **ElegooSlicer 1.5.3.5** (OrcaSlicer 2.4.2 fork), Windows:
  `D:\tools\ElegooSlicer\elegoo-slicer.exe`. User presets:
  `C:\Users\hypnodroid\AppData\Roaming\ElegooSlicer\user\default\{machine,process,filament}\`.
  System presets: `D:\tools\ElegooSlicer\resources\profiles\Elegoo\`.
- Presets matching his last successful print: printer **`Elegoo Centauri Carbon
  2 0.6 nozzle`**, process **`0.30mm Standard @Elegoo CC2 0.6 nozzle - Copy`**,
  filament **`PRUSA Strontium`** → inherits `Elegoo PETG PRO @ECC2`, **260 °C /
  85 °C, PETG**. Textured plate.

### Headless slicing — post-mortem, so nobody repeats it

Goal was `elegoo-slicer.exe --load-settings … --slice 0` from WSL. Findings:

1. The exe swallows stdout; `--help` prints nothing. Redirect to a file.
2. User preset JSONs have no `type` field → *"unknown config type"*. Adding
   `"type": "process"` etc. fixes that; removing `from` breaks it (*"from
   unsupported"*) — keep `"from": "User"`.
3. The CLI does **not** resolve a preset's `inherits` chain when handed a
   standalone file, so parent-only settings vanish and validation fails
   (*"Relative extruder addressing requires … G92 E0"*). `flatten_presets.py`
   walks and merges the chain. **Scope the index to the Elegoo vendor dir** —
   names like `fdm_machine_common` exist in every vendor and a global index
   resolves to another printer. Globbing all 11k vendor JSONs over `/mnt/d`
   also takes minutes.
4. With fully flattened presets it exits **239 with no output even at
   `--debug 5`**. Not solved. Aaron said drop it; he slices in the GUI.

If it ever matters again: the next thing to try is `--datadir` pointing at the
AppData folder with presets referenced **by name**, or exporting a `.3mf` project
from the GUI (his `stand.3mf` has a full `Metadata/project_settings.config`) and
slicing that.

## WSL notes

- `/mnt/d` and `/mnt/c` are 9P mounts — slow for recursive globs; fine for
  copying a few files.
- Windows executables run from WSL (`./elegoo-slicer.exe`) but want Windows
  paths (`D:\…`) in their arguments.
- `/usr/bin/node` is broken on this box; use `~/.local/node22/bin`. Not needed
  for this project.

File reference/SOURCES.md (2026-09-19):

# Reference drawings

Copied here so the project does not depend on waveshare.com staying up. Every
dimension used by `build_stands.py` was read off these images — neither board's
page states its outline in text.

| file | source URL | what it gives |
|---|---|---|
| `esp32-s3-lcd-1.28-outline.jpg` | [`/w/upload/e/ed/Esp32-s3-lcd-1.28-003.jpg`](https://www.waveshare.com/w/upload/e/ed/Esp32-s3-lcd-1.28-003.jpg) | R 18.25, chord 18.37, USB-C 12.81, 1.27 pitch, 27.00 span |
| `esp32-s3-lcd-1.28-pinout.jpg` | [`/w/upload/6/66/Esp32-s3-lcd-1.28-002.jpg`](https://www.waveshare.com/w/upload/6/66/Esp32-s3-lcd-1.28-002.jpg) | H1/H2 pin map, LCD and IMU signal assignments |
| `esp32-s3-touch-lcd-1.46-outline-coverglass.jpg` | [`/w/upload/a/ab/600px-...-introduction-04_1.jpg`](https://www.waveshare.com/w/upload/a/ab/600px-ESP32-S3-Touch-LCD-1.46-introduction-04_1.jpg) | glass Ø 44.77, stack 12.30, PCB 42.58/41.33, M2 holes |
| `esp32-s3-touch-lcd-1.46-outline-bare.jpg` | [`/w/upload/b/b8/600px-...-introduction-03_1.jpg`](https://www.waveshare.com/w/upload/b/b8/600px-ESP32-S3-Touch-LCD-1.46-introduction-03_1.jpg) | panel 39.36 × 41.53, stack 10.65, PCB 42.58/41.33 |
| `esp32-s3-touch-lcd-1.46-pinout.jpg` | [`/w/upload/7/72/600px-...-introduction-02_1.jpg`](https://www.waveshare.com/w/upload/7/72/600px-ESP32-S3-Touch-LCD-1.46-introduction-02_1.jpg) | 20-pin header map |

| `esp32-s3-lcd-1.28-switch-positions.png` | derived — disc fit + colour detection over the outline drawing | BOOT / RESET cap positions, ±0.5 mm |

Wiki pages: [ESP32-S3-LCD-1.28](https://www.waveshare.com/wiki/ESP32-S3-LCD-1.28) ·
[ESP32-S3-Touch-LCD-1.46B](https://www.waveshare.com/wiki/ESP32-S3-Touch-LCD-1.46B)
(one wiki page covers both 1.46 cover-glass options; there is no
`/wiki/ESP32-S3-Touch-LCD-1.46` — it 404s).

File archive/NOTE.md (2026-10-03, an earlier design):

Superseded files, kept rather than deleted.

- `esp32-s3-touch-lcd-146-stand.stl` — the first 1.46 stand, before it was clear
  the board ships in two cover-glass options. Byte-identical to what is now
  `stl/esp32-s3-touch-lcd-1.46-coverglass_board-44.77mm_stand.stl`,
  before the cable notch was added. Renamed away because an
  unqualified "146-stand" is easy to print by mistake.
- `gen_stand.py` — 1.28-only generator, superseded by `build_stands.py`, which
  reproduces its output exactly.
- `preview-side.png` — 1.28-only preview, superseded first by `preview-all.png`
  and now by `preview-stands.png`.
- `preview-all_pre-docks.png` — combined preview of the three low stands before
  the dock family existed. Superseded by `preview-stands.png` + `preview-docks.png`.
- `fit-test_pod-cup-1.28.stl`, `fit-test_pod-cup-1.46.stl` — bare pocket rings
  (09-18), never shipped. Superseded the same hour by `stl/cup-stand-1.28.stl`,
  which is the full pod cup on a desk base; they also predate the tab/header fix.
- `fit-test-pod-cups.png` — render of those rings.
- `cup-stand-1.28-section.png` — section render cut through the plug slot, so it
  showed no wall. Replaced by `renders/cup-stand-1.28-empty-front.png`.
- `pod-stl-duplicates/` — the old `pod/stl/` folder: copies of the pod, clips,
  rings and cup test that went stale whenever only `stl/` was rebuilt. Retired
  09-18 when STLs moved to `stl/small|large|pod/` with readable names; the live
  files are there.
- `Pocketwatch - back (v1, wrong header span).stl` — pocketwatch v1 back
  (10-03), built on a placeholder header span of 26 and a small cell. Its guides
  miss the real 30.0 headers. Superseded by the v2 plate + lid.

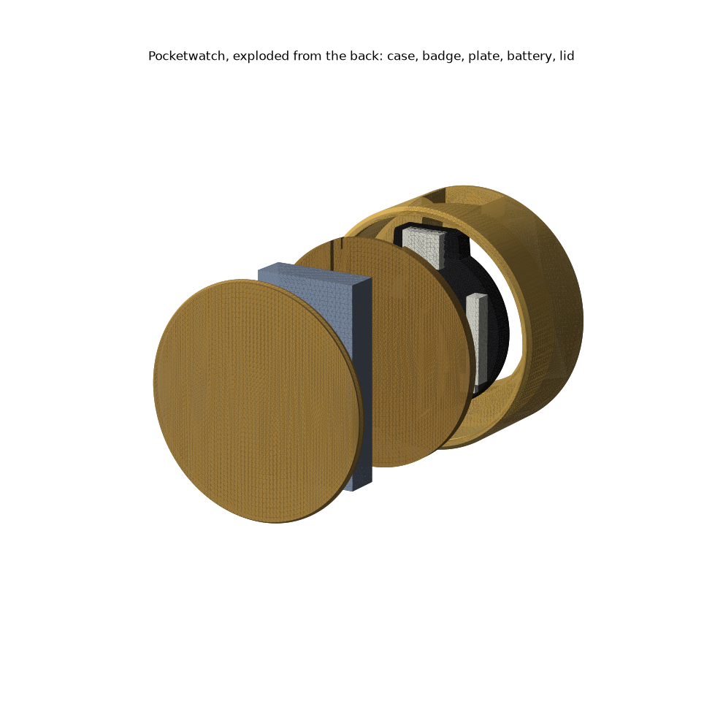
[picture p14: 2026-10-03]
pocketwatch/renders/exploded.png

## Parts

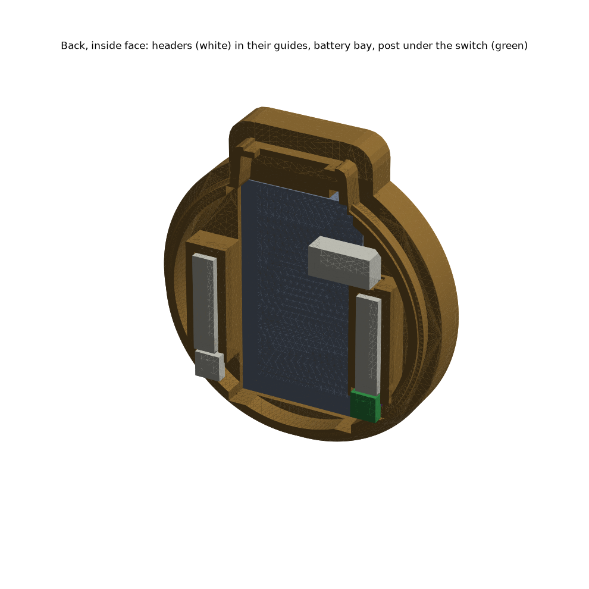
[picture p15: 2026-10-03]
pocketwatch/renders/back-inside-with-parts.png

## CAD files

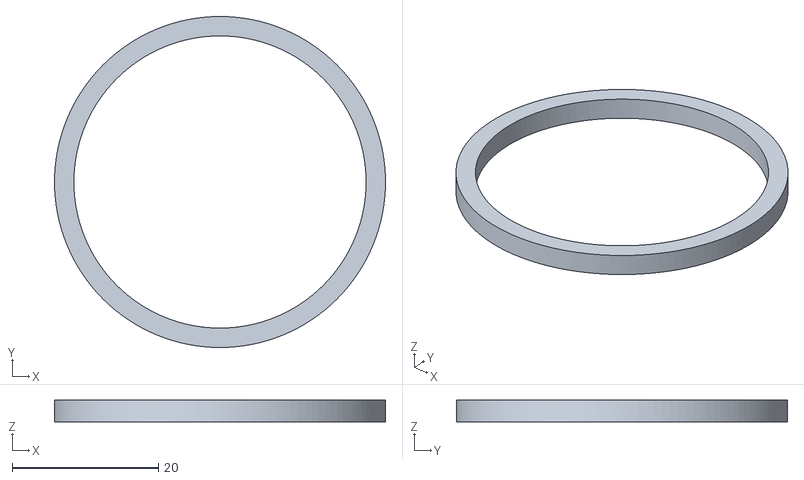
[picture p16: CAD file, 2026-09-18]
stl/large/Trim ring - large.stl
45.3 x 45.3 x 3.00

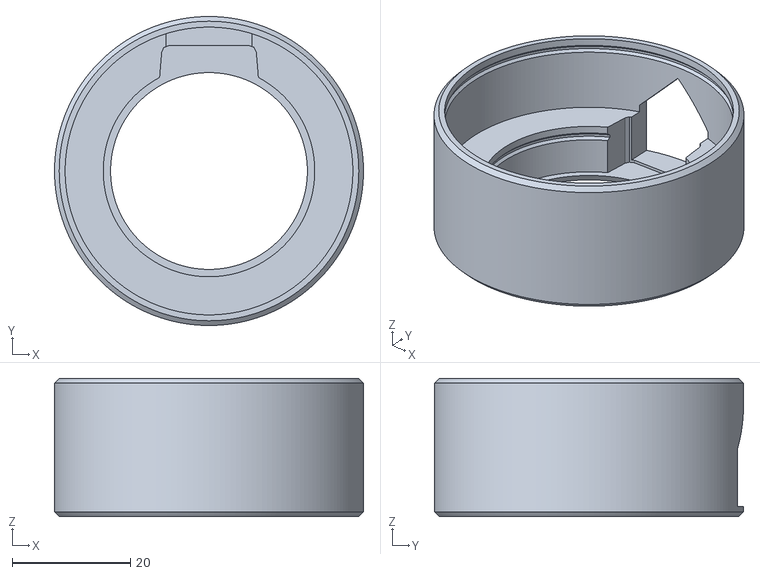
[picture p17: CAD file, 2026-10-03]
stl/pocketwatch/Pocketwatch - case.stl
52.3 x 52.3 x 23.4

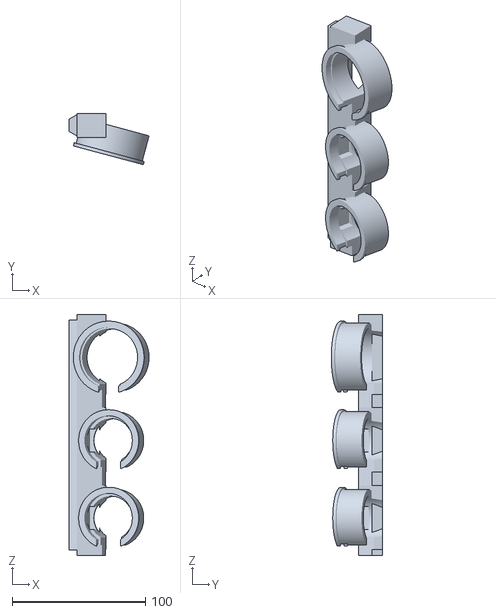
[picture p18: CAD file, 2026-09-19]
stl/pod/Pod - right-angle cables.stl
60.2 x 38.6 x 180.9

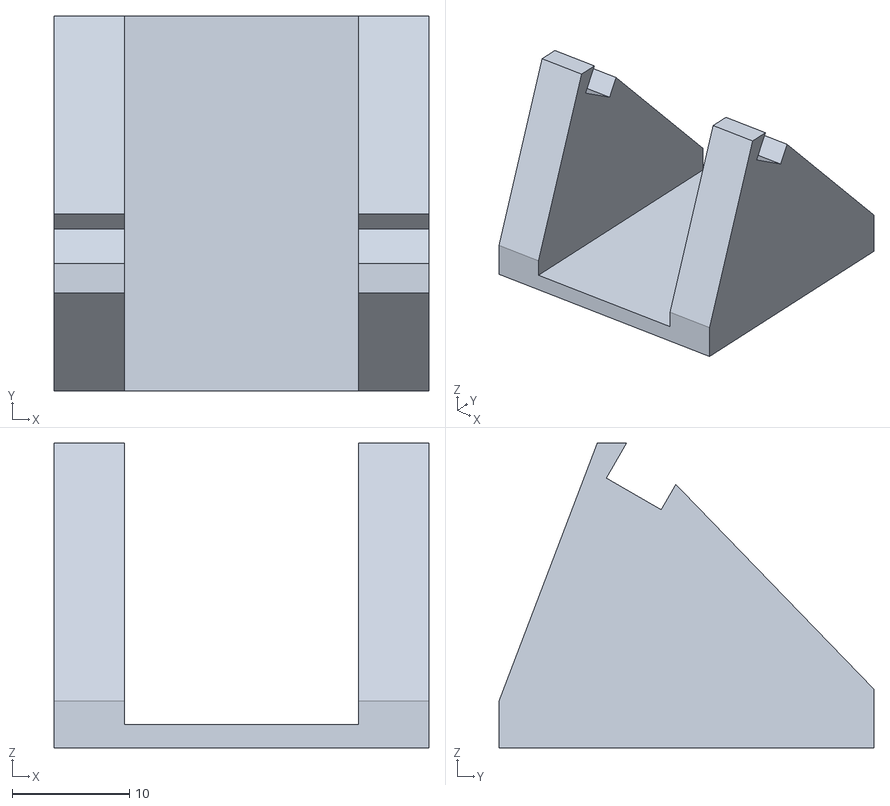
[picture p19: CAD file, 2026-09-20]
stl/small/Dock for right-angle cable - USB-C down.stl
32.0 x 32.0 x 26.0

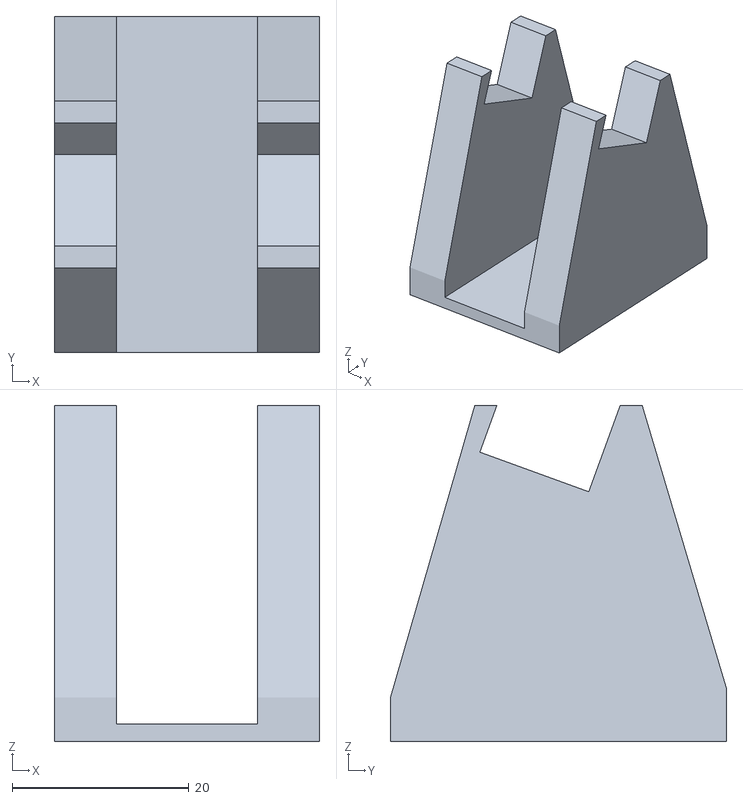
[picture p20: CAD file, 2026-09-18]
stl/large/Dock for straight cable - cover glass.stl
30.0 x 38.0 x 38.0

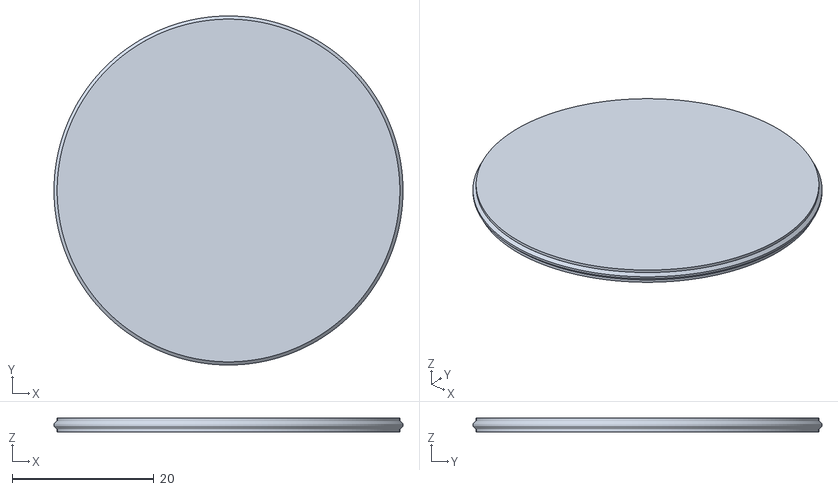
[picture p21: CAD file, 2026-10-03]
stl/pocketwatch/Pocketwatch - lid.stl
49.3 x 49.3 x 2.00

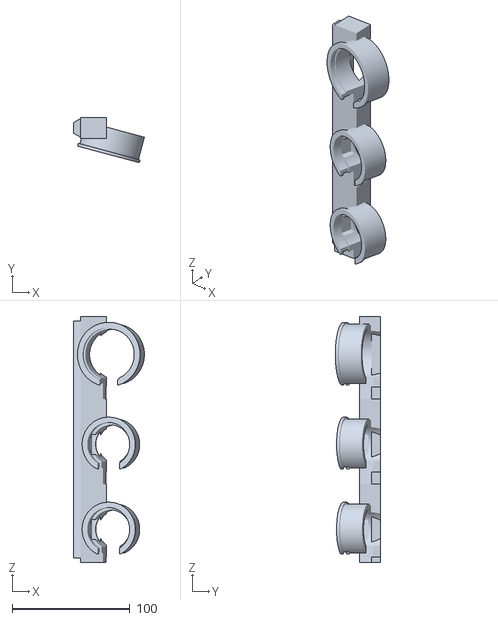
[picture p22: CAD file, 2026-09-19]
stl/pod/Pod - straight cables.stl
60.2 x 38.6 x 208.9

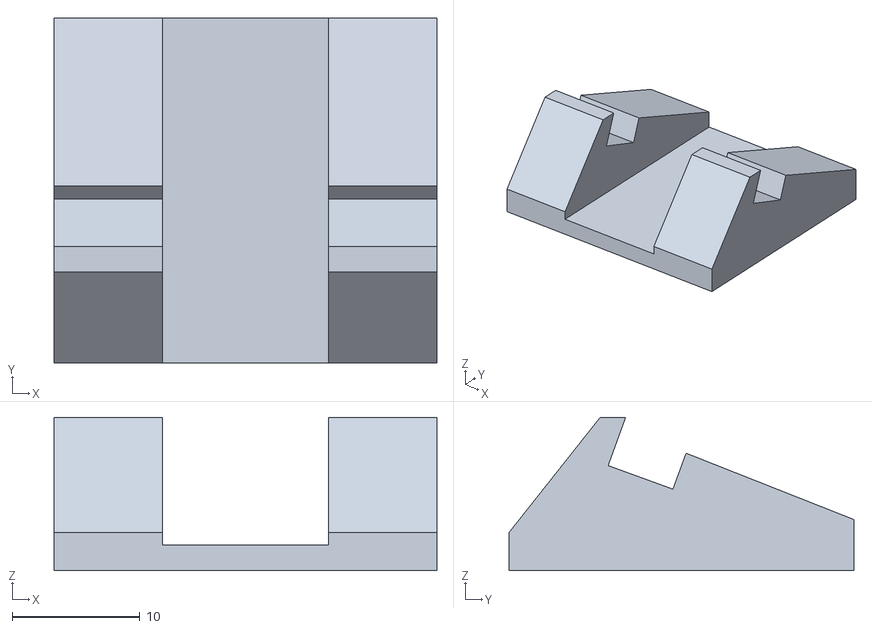
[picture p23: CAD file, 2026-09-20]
stl/small/Stand.stl
30.0 x 27.0 x 12.0

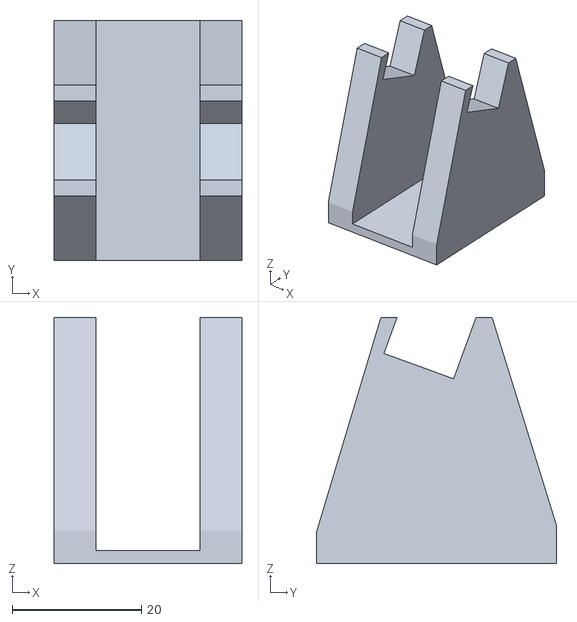
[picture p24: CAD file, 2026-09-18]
stl/large/Dock for straight cable - no cover glass.stl
29.0 x 37.0 x 38.0

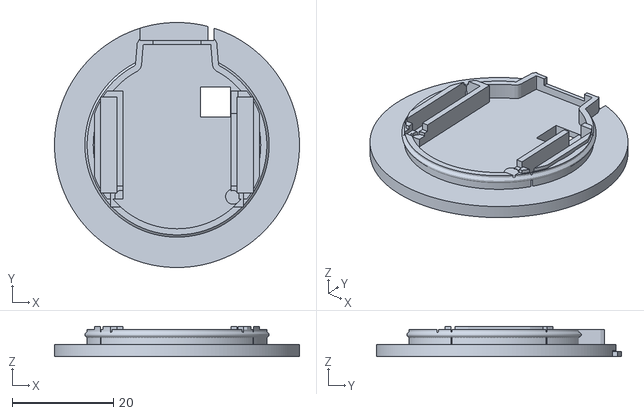
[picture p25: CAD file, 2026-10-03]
stl/pocketwatch/Pocketwatch - plate.stl
48.4 x 48.4 x 6.02

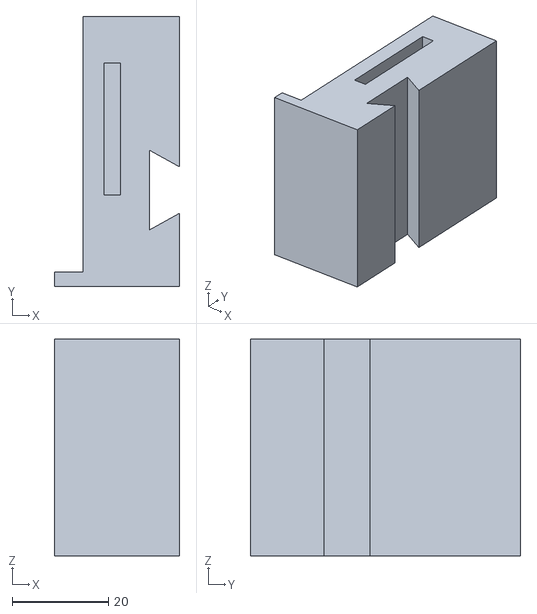
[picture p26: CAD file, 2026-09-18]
stl/pod/Clip - fixed jaw.stl
26.0 x 56.0 x 45.0

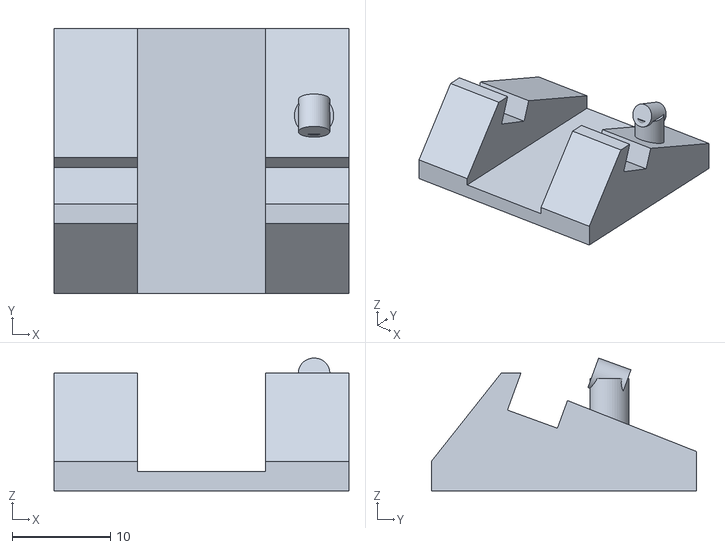
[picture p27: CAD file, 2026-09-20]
stl/small/Stand - BOOT button.stl
30.0 x 27.0 x 13.5

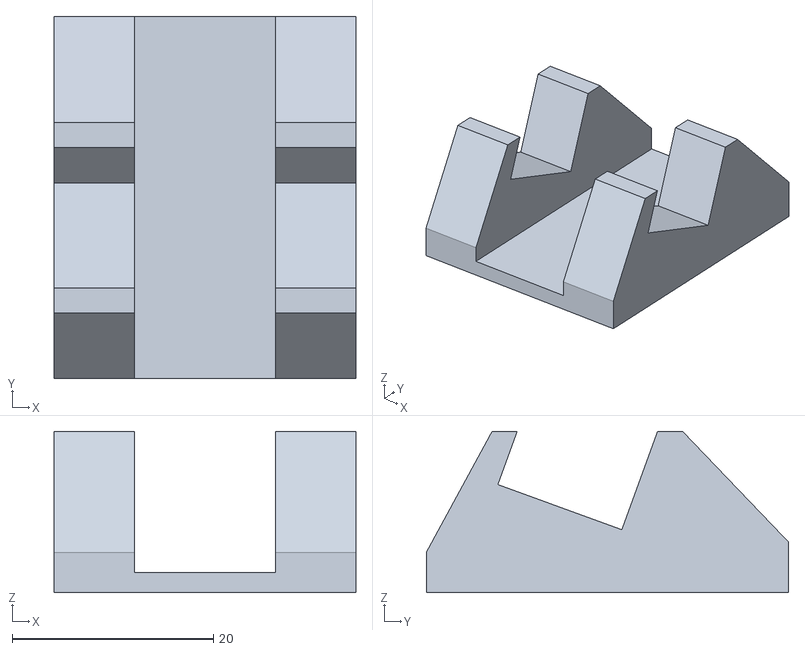
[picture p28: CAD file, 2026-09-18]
stl/large/Stand - cover glass.stl
30.0 x 36.0 x 16.0

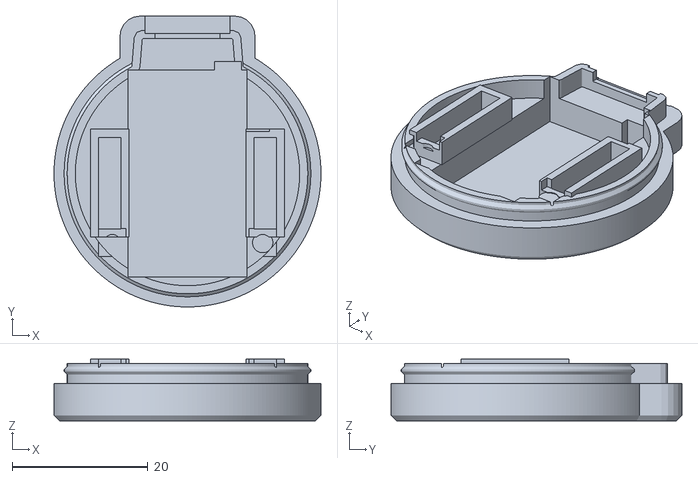
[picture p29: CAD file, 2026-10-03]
stl/pocketwatch/Pocketwatch - back.stl
39.4 x 42.9 x 9.12

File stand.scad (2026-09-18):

// Desk stands for Waveshare round display boards.
// Set `variant` below, then render. Mirrors build_stands.py exactly.
//
// Print flat on the base. No supports, no overhangs.
// Dimensions come from Waveshare's own outline drawings -- see reference/.

variant = "1.46-glass";   // "1.28" | "1.46-glass" | "1.46-bare"

//    board_d  thick   gap   lean depth base_d base_h fh bh  rh  W   slot_y nw  nf
P =
  variant=="1.28"      ? [36.50, 1.60, 2.40,20, 5.0, 27.0, 12.0, 3, 4, 2.0, 26, 12.0, 13, 2.0] :
  variant=="1.46-glass"? [44.77,12.30,13.10,20, 8.0, 36.0, 16.0, 4, 5, 2.5, 30, 16.0, 14, 2.0] :
  variant=="1.46-bare" ? [42.58,10.65,11.45,20, 8.0, 35.0, 16.0, 4, 5, 2.5, 29, 15.5, 14, 2.0] :
  undef;

board_d = P[0];  thick   = P[1];  gap        = P[2];  lean   = P[3];
depth   = P[4];  base_d  = P[5];  base_h     = P[6];  front_h= P[7];
back_h  = P[8];  ridge_half=P[9]; width      = P[10]; slot_y = P[11];
notch_w = P[12]; notch_floor = P[13];

eps = 0.01;

// horizontal offset from the groove centreline to a wall at z = base_h
wall_off = sin(lean)*(gap/2)*tan(lean) + cos(lean)*(gap/2);

module wedge() {
    rotate([90, 0, 90])
    linear_extrude(height = width)
        polygon([
            [0, 0], [base_d, 0], [base_d, back_h],
            [slot_y + wall_off + ridge_half, base_h],
            [slot_y - wall_off - ridge_half, base_h],
            [0, front_h]
        ]);
}

// the groove the board sits in
module groove() {
    translate([-eps, slot_y, base_h])
        rotate([-lean, 0, 0])
            translate([0, -gap/2, -depth])
                cube([width + 2*eps, gap, depth + base_h]);
}

// cable notch: straight through the ridge, front to back, so a USB-C lead
// can run through the stand instead of over it
module notch() {
    translate([(width - notch_w)/2, -eps, notch_floor])
        cube([notch_w, base_d + 2*eps, base_h - notch_floor + eps]);
}

difference() {
    wedge();
    groove();
    notch();
}

// Reference only -- the board in place. Uncomment to check clearances.
// %translate([width/2, slot_y - sin(lean)*depth, base_h - cos(lean)*depth])
//     rotate([-lean, 0, 0])
//         translate([0, 0, board_d/2])
//             rotate([0, 90, 0])
//                 cylinder(h = thick, d = board_d, center = true, $fn = 160);

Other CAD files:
stl/pod/Clip - slider.stl
stl/small/Stand - RESET button.stl
stl/large/Stand - no cover glass.stl
stl/small/Pod cup test.stl
archive/esp32-s3-touch-lcd-146-stand.stl
archive/fit-test_pod-cup-1.28.stl
archive/fit-test_pod-cup-1.46.stl
archive/pod-stl-duplicates/clip-slider.stl
archive/pod-stl-duplicates/cup-stand-1.28.stl
archive/pod-stl-duplicates/trim-ring-1.28.stl
stl/small/Slot fit gauge.stl
stl/small/Trim ring - small.stl

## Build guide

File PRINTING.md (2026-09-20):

# Printing these

## Pick the right file

First: **how will you power it?** That decides stand vs. dock.

| powering the 1.46 by… | print |
|---|---|
| straight USB-C cable in the bottom port | the **DOCK** |
| right-angle USB-C cable, battery, or port turned to the side | the low **stand** |

| board | low stand | dock |
|---|---|---|
| ESP32-S3-LCD-1.28 (SKU 26541) | [`small/Stand.stl`](stl/small/Stand.stl) | — (port is on the top chord) |
| ESP32-S3-Touch-LCD-1.46, **with** cover glass | [`large/Stand - cover glass.stl`](<stl/large/Stand - cover glass.stl>) | [`large/Dock for straight cable - cover glass.stl`](<stl/large/Dock for straight cable - cover glass.stl>) |
| ESP32-S3-Touch-LCD-1.46, **no** cover glass | [`large/Stand - no cover glass.stl`](<stl/large/Stand - no cover glass.stl>) | [`large/Dock for straight cable - no cover glass.stl`](<stl/large/Dock for straight cable - no cover glass.stl>) |

If you're unsure which 1.46 you have, see the "telling them apart" note in
[`BOARDS.md`](BOARDS.md). Printing the wrong one gives you a groove 1.65 mm out
— the glass version won't fit the bare stand at all.

## Slicer settings

Slice in the ElegooSlicer GUI with the same trio as the last successful print on
the machine (`ECC2_0.6_strontium-small-bear-2-WORKING-5x_PRUSA Strontium_0.3`):

| | preset |
|---|---|
| printer | `Elegoo Centauri Carbon 2 0.6 nozzle` |
| process | `0.30mm Standard @Elegoo CC2 0.6 nozzle - Copy` |
| filament | `PRUSA Strontium` |

`PRUSA Strontium` inherits `Elegoo PETG PRO @ECC2` — **PETG, 260 °C nozzle,
85 °C bed**, despite the name. Masses quoted below assume PETG at 1.27 g/cm³.

Nothing exotic is needed: 2 walls and 15 % infill (the process default) is
plenty. No supports. No brim needed — the base is flat and wide.

## Orientation on the plate

Print **flat on the base**, exactly as the STL is oriented (base on Z = 0).
Every face is either a vertical wall or an upward slope; there are no overhangs
anywhere, and the groove is a top-down cut. Do not stand them on end.

| stand | footprint | height | material |
|---|---|---|---|
| 1.28 | 26 × 27 mm | 12 mm | 3.6 cm³ ≈ **4.6 g** |
| 1.46 cover glass | 30 × 36 mm | 16 mm | 7.0 cm³ ≈ **8.9 g** |
| 1.46 bare | 29 × 35 mm | 16 mm | 6.5 cm³ ≈ **8.2 g** |
| 1.46 cover glass **dock** | 30 × 38 mm | 38 mm | 15.6 cm³ ≈ **19.8 g** |
| 1.46 bare **dock** | 29 × 37 mm | 38 mm | 14.1 cm³ ≈ **17.9 g** |

All five fit on the plate together with room to spare.

## The cable notch — what it does and doesn't do

Every stand has a notch cut straight through the middle of the ridge, front to
back, so a USB-C lead can run through the stand instead of draping over it. It
also sheds roughly a third of the material.

**On the low stands** the clearance under the rim is:

| stand | notch width | clear space under the board rim |
|---|---|---|
| 1.28 | 13 mm | **4.10 mm** |
| 1.46 cover glass | 14 mm | **5.36 mm** |
| 1.46 bare | 14 mm | **5.30 mm** |

**On the low stands that is a cable route, not a plug socket.** It takes a bare
lead or a right-angle USB-C plug. It will *not* take a straight plug pushed in
at bottom-dead-centre: the connector fires radially outward, so a straight plug
needs ~20–25 mm of run below the rim before the cable can turn — and there's
5 mm. That's exactly the failure you see when the board ends up lying across
the stand with a cable in it.

**The docks fix this by lifting the board.** Ridge 38 mm instead of 16, notch
widened to 16 mm for plug bodies, leaving **27 mm** under the rim — a 24 mm plug
body plus 3 mm for the cable to start its turn. The plug hangs down through
the notch — leaning forward as it goes, since the board leans back — and its
tip lands about 6 mm in from the front edge. The notch is open both ends: run
the cable out the front, or 32 mm back along the floor to exit behind. Cost:
roughly twice the material, and the screen sits ~72 mm off the desk instead
of ~50.

So, four ways to power these:

0. **Straight USB-C lead in the bottom port → print the dock.** Nothing to
   rotate, nothing to buy.

1. **Right-angle USB-C lead**, connector at the bottom, head sitting in the
   notch and the cable running out the back. Tidiest option.
2. **Rotate the board** so the connector sits clear of the groove entirely. The
   groove wraps about ±50° either side of bottom-dead-centre, so anything past
   roughly 4 or 8 o'clock is in free air and takes a straight plug. Then drop
   the slack into the notch. The display rotates in software (LVGL).
3. **Battery.** Both boards have a battery connector — the 1.28 an MX1.25 2-pin,
   the 1.46 a BAT pin on the header — so neither has to be tethered at all.

Board-specific notes:

- **1.28** — USB-C sits on the flat chord. Chord at the top is its natural
  orientation and needs no notch at all; chord at the bottom puts the connector
  into the notch, which is what the notch is there for.
- **1.46** — USB-C is on the bottom edge and plugs in downward, so this board is
  the one that actually needs the notch. Seated naturally, use a right-angle
  lead; otherwise rotate per option 2.

Because the board is unsupported across the notch it sinks about 1.2 mm lower
than it otherwise would, which is accounted for in the numbers above and
actually *increases* groove engagement slightly.

## The 1.28 button-post stands

`small/Stand - BOOT button.stl` and `small/Stand - RESET button.stl` are the plain 1.28 stand
with one addition: a Ø3.2 pad on a Ø4 column, standing 3.1 mm out of the right
(BOOT) or left (RESET) shoulder, exactly behind that switch on the badge's back.

**How it clicks.** The badge leans back in its groove, resting on the groove's
rear lip 5 mm up its rim. The switch is 7.7 mm up — 2.7 mm above that lip — and
the pad is placed from the groove's *front* wall, so it can never hold the
switch down; the badge simply leans back onto it. Press anywhere near the top of the screen and
the badge tries to rotate about the lip; the switch is the softest thing in the
load path, so it is what compresses. Because the switch is so close to the
pivot, a push at the top is levered **~11×** onto it: a light tap does it. The
badge's own weight puts ~30 gf on the pad — well under the ~160 gf a tactile
switch needs — so it doesn't self-press.

**Seat it USB-C chord up.** The badge is round and rotates freely, and the post
only works in one orientation: chord at the top puts BOOT at the lower right and
RESET at the lower left, as you look at the screen.

Which switch: **BOOT is GPIO0**, the one firmware reads as a user button. RESET
reboots the board — useful, but not for tapping.

Switch positions were measured off Waveshare's outline drawing —
`reference/esp32-s3-lcd-1.28-switch-positions.png` shows the fit. The Ø3.2 pad
is there to forgive ±1 mm of that measurement. If the first print misses, the
two numbers are `SWITCH` and `REST_CLR` in `build_stand_button.py`
(`~/.venvs/cad/bin/python build_stand_button.py BOOT`).

## If your board has header pins fitted

Waveshare's drawing shows a bare board, but these commonly ship with (or get
fitted with) a 2×10 header whose pins protrude several mm out of the **back**.
Those pins stick out perpendicular to the board, straight at the stand.

Where the header sits when you seat the board decides whether it fits. Measured
against the cover-glass stand, clearance by header position — angle measured
from bottom-dead-centre, where the USB-C sits:

| header at | 5 mm pins | 8 mm pins | 11 mm pins |
|---|---|---|---|
| 0° (bottom, over the notch) | 7.8 mm | 6.8 mm | 5.8 mm |
| 20° | **clash** | **clash** | 0.5 mm |
| 40° | **clash** | **clash** | 0.2 mm |
| 50° | **clash** | 0.2 mm | 2.2 mm |
| 60° | 1.0 mm | 3.0 mm | 4.8 mm |
| 75° | 5.5 mm | 7.5 mm | 9.5 mm |
| 90° (side) | 11.5 mm | 13.5 mm | 19.7 mm |
| 180° (top) | 29.2 mm | 30.0 mm | 29.0 mm |

**Keep the header out of the 20°–50° band either side of bottom.** That arc is
where the groove and its shoulders are, and pins there have nowhere to go.
Bottom-dead-centre is fine because the notch removes the ridge; past about 60°
the board has risen clear of the stand entirely.

In the board's natural orientation — USB-C at the bottom — the header lands
around 75–90°, which clears comfortably. The trap is a *partial* rotation: turn
the board 30° or so to angle the USB-C and you walk the header straight into
the shoulder.

**The docks are far more forgiving here.** Their rear ramp drops 32 mm over
~10 mm of depth, so it falls away from the pins fast; measured against the
cover-glass dock, nothing clashes at any angle — worst case is 0.8 mm at 40°
with 5 mm pins, and 8 mm pins clear by 8 mm+ everywhere.

## If the fit is wrong

`fit` — the slop added to the board's thickness — is 0.8 mm on the 1.46s; the 1.28's groove is 5.4 mm (the fit gauge's 5.0 slot + 0.4, because the leaned groove walls stair-step into the slot). It is
the only number likely to need touching. A 0.6 mm nozzle tends to come out
slightly undersized, which is why it starts generous.

Edit the relevant entry in `build_stands.py` (`gap = <thickness> + <fit>`), then:

```
python3 build_stands.py
python3 check_stl.py "stl/large/Stand - cover glass.stl"
```

- rattles → drop to 0.5
- won't seat, or the ridge creaks → go to 1.0

`check_stl.py` exits non-zero if the mesh came out unwatertight, so it is worth
running before every slice.

## Automating the slice — unfinished

Driving `elegoo-slicer.exe` headless from WSL was attempted and abandoned. Two
obstacles were solved and are captured in `flatten_presets.py`:

1. ElegooSlicer's user presets omit the `type` field the CLI demands, and it
   also rejects a preset with no `from` field.
2. The CLI does not resolve a preset's `inherits` chain when the preset is
   handed to it as a standalone file, so parent-only settings (`layer_gcode`,
   `use_relative_e_distances`, …) silently vanish and slicing dies on a
   validation error. `flatten_presets.py` walks and merges the chain, scoped to
   the Elegoo vendor — a global index is wrong, because names like
   `fdm_machine_common` are reused across vendors and resolve to another
   printer's preset.

A third failure was not solved: with fully flattened presets the CLI exits 239
and prints no diagnostic at all, even at `--debug 5`. Slicing in the GUI is the
supported path for now.

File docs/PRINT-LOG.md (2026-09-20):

# Print log

What has actually come off the printer, and what happened. **Add an entry
before changing any number in response to a print.** Newest first.

Template:

```
## YYYY-MM-DD — <part> (<file>)
- material / presets:
- result:
- fit numbers to change (if any):
- photo:
```

---

## 2026-09-20 — 1.28 BOOT button stand, 5.4 mm groove (`small/Stand - BOOT button.stl`)
- material / presets: black filament — not the usual blue; presets not stated
- result: **the badge seats.** Two photos. Side-on: rim fully down in the
  groove, a little slack in front of the glass, badge leaning back. From
  behind: the post stands on the lower-left switch (BOOT, seen from the back);
  the pad looks perhaps ~1 mm inboard of the switch centre, but the shot is
  blurred and the post is nearer the lens than the switch, so not trusted.
  The column printed with a rough, leaning top (a Ø4 column alone at 0.6 mm).
- **then he pressed it: no click.** "the bottom white plastic around the button
  itself is pushed up against the back wall, so the arm can't reach." Third
  photo, side-on in his hand. Measured the switches off his own back-view photo
  rather than guessing again: they are at r **15.5**, only **2.7 mm in from the
  rim** — the drawing said r 12.2. So the housing sits **below** the groove's
  rear lip and cannot enter a 5.4 mm groove at all; the badge was propped proud
  and shoved forward, which is also why the post could not reach.
- also seen: H1/H2 are fitted with tall female sockets. The pod's 1.28 cups
  already relieve for them (`hdr`, ~8.5 off the PCB) — no change.
- fit numbers to change: not a fit number — a design fault. 1.28 gains
  `rear_lip = 3.0` (the groove's rear wall stops short of the ridge so the
  switch housings clear, and the pivot drops so a press has travel),
  `width` 26 → 30 (the switches are at |x| 11.45; the post needs shoulder), and
  `SWITCH` in `build_stand_button.py` is now the measured pair. Details in
  DESIGN.md.
- photo: sent in chat 2026-09-20 (black print on the bamboo desk; side view, and from behind).

## 2026-09-20 — 1.28 button-post stand, 5.0 mm groove (`small/Stand - … button.stl`)
- material / presets: presumed the usual (PETG, ECC2 0.6 / 0.30 mm)
- result: **"just barely too narrow."** The gauge's 5.0 slot took the badge but
  the stand's 5.0 groove does not: the groove leans 20°, so its walls print as
  0.3 mm stair-steps that each reach ~0.1 mm into the slot, which the gauge's
  slots do not have.
- his worry: once the slot is wide enough the badge will sink and the post
  won't reach the button. Height is set by the groove *floor*, not its width —
  but the post was placed from the groove centre with no check that the badge
  can rock far enough to click. Checked, see fit numbers.
- fit numbers to change: 1.28 `gap` 5.0 → **5.4**. Button pad re-placed from the
  groove's front wall (was: from its centre) — press travel at the switch
  0.10 mm at the old 5.0 → **0.8 mm**, now asserted. Details in DESIGN.md.
- photo: none

## 2026-09-18 — fit gauge (`small/Slot fit gauge.stl`)
- material / presets: presumed the usual (PETG, ECC2 0.6 / 0.30 mm)
- result: **printed.** Photo from behind: the 1.28 stands seated in the **5th
  slot from the narrow end = 5.0 mm** (read by counting walls; the dots weren't
  visible). The back of the board is bare — **no case**. The thickness at the
  rim is the round display module on the front of the PCB, which reaches
  almost to the PCB edge. The earlier "case" reading was wrong.
- fit numbers to change: 1.28 `gap` 2.7 → **5.0**, `thick` 1.6 → **4.7**
  (PCB + module, estimated between the 4.5 slot and the 5.0 slot; sets where
  the button post lands).
- photo: sent in chat 2026-09-18 (blue gauge on the bamboo desk, board seen from behind).

## 2026-09-18 — 1.28 button-post stand, second report (photo)
- result: **still too narrow.** Photo: the badge rests *on top of* the groove,
  it does not enter it. *(Read at the time as a case — wrong, see the gauge
  entry above: it is the display module.)* Seen in the photo: black
  glass, white serrated gasket, a dark bezel ring, a dark back plate, and white
  button nubs sticking out of the rim. The rim is several mm thick, not the
  1.6 mm bare PCB the stand was designed for. The 2.4 → 2.7 widening was
  solving the wrong problem.
- fit numbers to change: unknown until measured. Printed
  `stl/small/Slot fit gauge.stl` requested to get the real width.
- also: the case changes where BOOT/RESET are reached from — the post may be
  landing on a button nub rather than behind the switch. Not redesigned yet.
- photo: sent in chat 2026-09-18 (blue print, badge held above it, seen edge-on).

## 2026-09-18 — 1.28 button-post stand (`…1.28_board-36.5mm_stand_*-post.stl`)
- material / presets: not stated
- result: **printed.** The groove the badge lays in is slightly too small.
- fit numbers to change: groove 2.4 → **2.7 mm** (board 1.6 + 1.1 fit, was
  + 0.8). Shared with the plain 1.28 stand, which gets the same change.
- photo: none

## 2026-09-18 — 1.46 cover-glass low stand (`…coverglass_board-44.77mm_stand.stl`)
- material / presets: PETG (`PRUSA Strontium`), ECC2 0.6 / 0.30 mm, textured plate
- result: **printed and photographed.** Board seats in the groove and stands
  cleanly with no cable. With his straight USB-C cable plugged into the bottom
  port the board cannot seat — it ends up lying across the stand (5 mm under
  the rim vs a ~24 mm plug body). This was the documented limitation; he wanted
  it fixed, not documented → **docks** added the same day.
- fit numbers: none reported for the groove itself — it fit.
- photo: sent in chat 2026-09-18 (light-blue print on a bamboo desk, next to a
  keyboard; second photo with the cable in and the display showing CYBER-PUCK).

## Not yet printed
- 1.28 low stand, 1.46 bare stand, both docks, the other button-post stand
- pod, trim rings, clips — **print the rings and clips first** (10 min) to
  check the press fit and tongue clearance before committing ~40 g to the pod

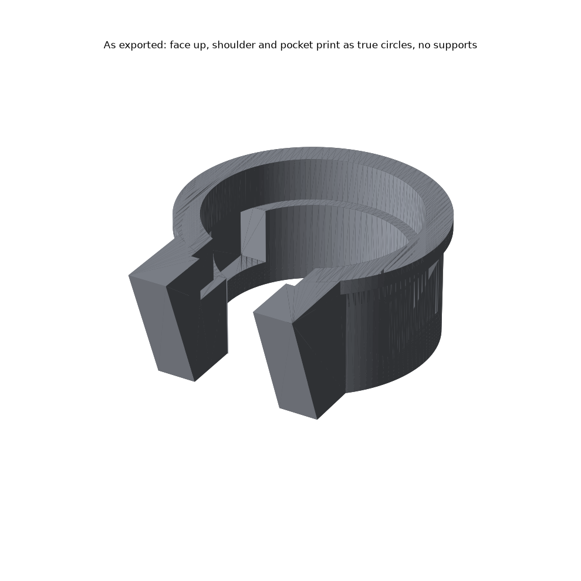
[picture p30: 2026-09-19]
renders/cup-stand-1.28-as-printed.png

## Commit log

2026-09-18 Desk stands for three Waveshare round display boards
    Angled wedge stands with a cable notch, for:
    - ESP32-S3-LCD-1.28 (SKU 26541), non-touch GC9A01
    - ESP32-S3-Touch-LCD-1.46, with cover glass
    - ESP32-S3-Touch-LCD-1.46, without cover glass
    The 1.46 ships in two cover-glass options that are genuinely different parts
    (Ø44.77/12.30mm vs Ø42.58/10.65mm), so both get their own stand.
    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
    [esp32-s3-lcd-128-stand.stl, esp32-s3-touch-lcd-146-stand-bare.stl, esp32-s3-touch-lcd-146-stand-coverglass.stl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]
2026-09-18 Document header-pin clearance by seating angle
    Waveshare's outline drawing shows a bare board, but these commonly have a 2x10
    header fitted whose pins protrude out of the back, straight at the stand.
    Clearance measured against the cover-glass stand: bottom-dead-centre is fine
    (the cable notch removes the ridge there) and past ~60 degrees the board has
    risen clear, but the 20-50 degree band either side of bottom is a hard clash for
    5-8mm pins -- that arc is exactly where the groove shoulders are.
    Natural orientation (USB-C down) puts the header at ~75-90 degrees and clears.
    The trap is a partial rotation.
2026-09-18 Move printable STLs into stl/ with self-describing names
    Each filename now carries the board it fits and that board's outside diameter,
    so the three sizes are distinguishable without opening them:
    stl/esp32-s3-lcd-1.28_board-36.5mm_stand.stl
    stl/esp32-s3-touch-lcd-1.46-bare_board-42.58mm_stand.stl
    stl/esp32-s3-touch-lcd-1.46-coverglass_board-44.77mm_stand.stl
    This matters most for the two 1.46 files, which are not interchangeable -- the
    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
    [esp32-s3-lcd-1.28_board-36.5mm_stand.stl, esp32-s3-touch-lcd-1.46-bare_board-42.58mm_stand.stl, esp32-s3-touch-lcd-1.46-coverglass_board-44.77mm_stand.stl]
2026-09-18 Add dock variants for a straight USB-C plug in the 1.46's bottom port
    The printed low stand exposed the limit the docs already described: with a
    straight cable in the bottom port the board cannot seat, because the plug body
    (~24mm) needs to hang radially below the rim and there was 5mm. Documenting
    that was not a fix.
    Two new STLs lift the board instead. Same groove and notch (notch widened to
    16mm for plug bodies), ridge raised 16 -> 38mm, groove moved 3mm back so the
    plug tip lands inside the base rather than on its front edge. 27mm clear under
    the rim: a 24mm plug plus 3mm for the cable to turn. Notch is open both ends so
    the cable exits front or back.
    Also: header-pin clearance re-meas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
    [esp32-s3-touch-lcd-1.46-bare_board-42.58mm_DOCK-straight-plug.stl, esp32-s3-touch-lcd-1.46-coverglass_board-44.77mm_DOCK-straight-plug.stl]
2026-09-18 Add the gauge pod: pillar-pod cluster clipped to a monitor edge
    The stands were the warm-up. This is the goal: three round displays as an
    instrument cluster on the side of a monitor, with the look of a 2G DSM
    A-pillar pod -- cylindrical cups with trim rings, gauges canted 15 degrees
    toward you, stacked on a spine. Adapted to a flat monitor edge; no attempt to
    mimic a windshield pillar's curve.
    Parts (pod/stl):
    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
    [clip-fixed.stl, clip-slider.stl, pod-gap12.stl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]
2026-09-19 Pod: gap12 is the default now that the cables are right-angle
    Right-angle USB-C cables bought, so the 12 mm gap pod (181 mm) becomes the
    primary and gap26 (209 mm, straight plugs) the alternative.
    Two things a right-angle plug needs that the pod did not have:
    - a wider drop slot at each cup bottom: 11 -> 16 mm, 12 mm deep, for a
    head ~12 x 6.5 x 9 mm
    - a way from the drop zone into the wiring channel. The slot used to dump
    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
    [pod-gap12.stl, pod-gap26.stl]
2026-09-19 1.28 stand with a button post: press the screen, click BOOT
    Two new STLs: the plain 1.28 stand plus a short post behind the badge placed
    exactly behind its BOOT (or RESET) tactile switch. Pressing the screen rocks
    the badge back in its groove onto the post; the switch is the softest thing
    in the load path, so it compresses and clicks.
    Mechanics: the badge leans on the groove's rear lip 5 mm up its rim and the
    switch is 7.7 mm up, so a push at the top of the screen is levered ~11x onto
    the switch. Its own weight puts ~30 gf on the pad, well under actuation.
    Switch positions measured off Waveshare's outline drawing by fitting the disc
    (R 18.25) and locating the two caps: BOOT back-view (-9.0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
    [esp32-s3-lcd-1.28_board-36.5mm_stand_BOOT-post.stl, esp32-s3-lcd-1.28_board-36.5mm_stand_RESET-post.stl]
2026-09-19 Docs and skills for whoever works on this next
    Agent brief (CLAUDE.md), a design-decisions log that records what each
    choice replaced (docs/DESIGN.md), the toolchain with venv setup and the
    slicer-CLI post-mortem so nobody repeats it (docs/TOOLCHAIN.md), a print log
    with the one real print so far (docs/PRINT-LOG.md), and build_all.sh --
    rebuild, validate every mesh, re-render, link-check all docs, in one command.
    Five project skills under .claude/skills/, each the procedure that actually
    ran during the build rather than an idealised one:
    rebuild-and-ship build_all -> look at renders -> commit -> push -> mirror
    add-board drawing -> verified dimensions -> BOARDS row -> build
    me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
    [clip-fixed.stl, clip-slider.stl, pod-gap12.stl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]
2026-09-19 1.28 groove 2.4 -> 2.7 mm: button-post print was too tight
    [esp32-s3-lcd-1.28_board-36.5mm_stand.stl, esp32-s3-lcd-1.28_board-36.5mm_stand_BOOT-post.stl, esp32-s3-lcd-1.28_board-36.5mm_stand_RESET-post.stl]
2026-09-19 Fit gauge for the 1.28 groove: his badge is cased, rim is not 1.6 mm
    [fit-gauge_groove-3.0-to-6.5mm.stl]
2026-09-19 1.28 groove 5.0 mm from the fit gauge: display module makes the rim ~4.7 thick
    [esp32-s3-lcd-1.28_board-36.5mm_stand.stl, esp32-s3-lcd-1.28_board-36.5mm_stand_BOOT-post.stl, esp32-s3-lcd-1.28_board-36.5mm_stand_RESET-post.stl]
2026-09-19 Pod: seat the 1.28 as its real 4.7 mm rim stack, not the bare 1.6 PCB
    [pod-gap12.stl, pod-gap26.stl]
2026-09-19 Cup stand: one 1.28 pod cup on a desk base, to test the pod's cup
    cup() pulled out of pod() (pod STL byte-identical after the refactor).
    Rendering the cup against the drawing caught two things that would have
    made the 1.28 unseatable in the pod: the USB-C tab reaches r 21.1 (outside
    the pocket) -- notched, tab down into the plug slot; H1/H2 headers reach
    r ~17 against a 16.5 bore -- relieved through the shoulder. pod/stl/ is now
    kept in step with stl/ (it held stale copies).
    [cup-stand-1.28.stl, fit-test_pod-cup-1.28.stl, fit-test_pod-cup-1.46.stl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]
2026-09-19 Organize STLs by badge size with readable names
    stl/small/ (1.28), stl/large/ (1.46), stl/pod/. Names are plain English
    ("Stand - BOOT button.stl"); large/ files still say cover glass / no
    cover glass. Builders write the new paths directly; rebuilt output is
    byte-identical to the moved files. Stale pod/stl/ copies archived.
    [Clip - fixed jaw.stl, Clip - slider.stl, Dock for straight cable - cover glass.stl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]
2026-09-20 1.28 groove 5.0 -> 5.4; button pad placed from the front wall, press travel asserted
    The 5.0 stand printed just barely too narrow: the leaned groove walls
    stair-step into the slot, the gauge slots do not. Widening also fixes a
    latent fault: at 5.0 the badge could rock only 0.10 mm at the switch before
    bottoming out, so BOOT/RESET would not have clicked. Pad now sits REST_CLR
    off the cap with the badge upright against the front wall: 0.8 mm travel.
    [Stand - BOOT button.stl, Stand - RESET button.stl, Stand.stl]
2026-09-20 Print log: 5.4 mm BOOT stand seats the badge; click not yet confirmed
    Claude-Session: https://claude.ai/code/session_01H9ws9Nyoa4VGHhn154ro46
2026-09-20 1.28: stop the groove rear wall short -- the switches are at the rim, not r 12
    Measured BOOT/RESET off Aarons own back-view photo: r 15.5, 2.7 mm in from
    the rim, where the drawing put them at r 12.2. At that radius the switch
    housing sits below the groove rear lip, and since it stands ~1.7 mm off the
    PCB the badge is ~6.4 mm thick there -- it cannot enter a 5.4 mm groove at
    any depth. That propped the badge proud and forward, so the post could not
    reach the button.
    New rear_lip parameter stops the rear wall 3.0 mm up the board (front wall
    untouched, badge still held 5 mm deep). Housings clear by 1.8 mm and the
    pivot drops, taking press travel at the switch from 0.02 mm to 1.33 mm.
    width 26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
    [Stand - BOOT button.stl, Stand - RESET button.stl, Stand.stl]
2026-09-20 1.28 dock: badge turned over, USB-C down, for the right-angle cable
    Turning the badge over moves three things at once, so this is a new part,
    not a parameter. The USB-C sits on a tab that sticks 2.85 mm past the disc,
    so tab-down the tab and the plug both hang into the cable notch: 13 -> 20 mm
    to pass the 18.37 mm tab. BOOT/RESET go to the top, out of the groove. The
    headers and battery JST come down instead, so rear_lip 2.5 keeps the rear
    wall below them.
    Leaning 30 deg rather than 20 points the port down-and-forward, so the plug
    tucks into the notch instead of needing headroom under the rim -- 26 mm at
    the ridge instead of ~30.
    build_stand_usbdown.py checks it as solids: badge, tab, plug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
    [Dock for right-angle cable - USB-C down.stl]
2026-10-03 Pocketwatch case for the 1.28 badge: case + snap-in back
    Round case with a bezel lip and a pendant at 12 o'clock that the
    right-angle USB-C plug pushes into (the plug is the crown). The badge
    floats axially; pressing the screen slides it 0.20 onto a post on the
    back, and 0.25 more clicks BOOT. Everything else keeps 0.70 of room.
    The back snaps into a groove in the case bore and carries header guides
    (0.15/side, free axially), the BOOT post, a RESET pocket and a 401730
    battery bay behind the header tops.
    Every solid is generated from two tables (Badge = measured, Case =
    chosen). Both parts are raw shape minus each badge feature's keep-out.
    Placeholders are field metadata and print at the to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
    [Pocketwatch - back.stl, Pocketwatch - case.stl]
2026-10-03 Pocketwatch v2: measured header span, 1000 mAh chamber, three parts
    v1 used placeholder header span 26 and a small cell, so its guides would
    miss the real headers. v2 uses the measured 30.0 span; guides grip in x
    only and are open in y, so the unmeasured header height does not matter.
    The 42.65 mm cell needs a 48.7 mm chamber, so the case is now case +
    plate (snaps into the badge bore, carries guides and the BOOT post) +
    lid (snaps into the chamber). 12 o clock recess takes any straight
    USB-C cable. A lead channel in the plate gets the battery wire past the
    battery to the JST. All solid checks pass; three STLs watertight.
    Claude-Sessio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
    [Pocketwatch - back (v1, wrong header span).stl, Pocketwatch - case.stl, Pocketwatch - lid.stl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]
2026-10-03 Pocketwatch README for v2: three parts, print orientation, assembly order
    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
2026-10-03 Pocketwatch case: 45-degree arch over the USB-C recess, no floating bridge
    The chamber wall spanned the 14 mm recess as a flat ceiling at z 11.55
    (print), which the slicer left floating. A pointed 45-degree arch above
    the recess is self-supporting. The build now fails any part whose
    overhang points sit more than 2 mm from supported material, checked in
    print orientation; it flags the old case and passes all three parts.
    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
    [Pocketwatch - case.stl]
2026-10-13 Pocketwatch bore fit gauge: four front rings at RAD_CLR 0.25-1.15
    v2's badge stopped on the plate step, ~10 mm behind the bezel, instead of
    reaching the lip. Logged in PRINT-LOG. The gauge is the case front only
    (lip, bore, tab slot) so the fit can be found in a 10-minute print.
    Claude-Session: https://claude.ai/code/session_01PaLTAN4AhK7wN7RKu7ALz8
2026-10-13 Pocketwatch: RAD_CLR 0.25 -> 1.15 from bore gauge print (only ring 4 fit)
2026-10-13 Pocketwatch case: chamfered 3.8 mm flat roof over the USB-C recess instead of a pointed arch
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2026-10-13 Pocketwatch: allow 8 mm bridges (BRIDGE_MAX); USB-C recess roof 7.8 mm flat, lower
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2026-10-13 USB-only case: crown boss around the tab, metal-shell slot (9.6 x 4.3), flat roof
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2026-10-13 Plate disc clearance 0.18 -> 0.65 per side (printed ~1 mm too large); USB-only and hoop plates
    Claude-Session: https://claude.ai/code/session_01G2nUqFRSgJDyNXsVszfiGa
2026-10-13 Plate: keep the 0.18 clearance as default, add roomy (0.65) variants as separate files; hoop likewise
    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
2026-10-13 Hoop: snug (0.12) and medium (0.18) base variants after the 0.25 mortise printed loose
    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
2026-10-13 Hoop: snap arms replace the M3 screw; button (flexure) back plate; screw version archived
    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
2026-10-13 Button plate: drop the back-face dimple (printed melted on the bed); the U-slot marks the tab
    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
2026-10-13 Hoop front-BOOT: base key and one-piece flexure rocker press the button tab from the front
    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
2026-10-13 Board: measured schematics (side, rocker section, front elevation) generated from the hoop CAD
    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
2026-10-14 Hoop v2 after the print: deeper front-BOOT stop, bigger nub, tighter mortise; wider USB-C slot everywhere
    The front-BOOT print was close: the lever and the hoop flex more than the
    spring model says, so the click arrived at or past the 0.25 mm of spare key
    travel. The stop is now 1.0 mm past the worst-case click (key stop 2.7 ->
    3.4 mm) and the nub is Ø4.4, 2.0 proud (was Ø3.2, 1.4) so it finds the tab
    for sure. The model's stop force rises to 7.4 N, so the key-force ceiling is
    8 N and the twist check now loads the pad with the stop force, the most the
    rocker can carry before the pad rests on the tier.
    The case was loose on the stand at 0.12 per side with the snap tenon:
    Stand.FIT 0.08 (sn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
2026-10-14 Pendant: minimal crown-bump case for a child, button plate and a twist-lock kid button (PLA)
    A no-frills version of the USB-only case for a pendant: Ø43.6 × 12.45 with the
    crown bump, and the USB-C slot as its only opening. The back plate's BOOT tab is
    longer and wider (21 mm, 4.4 → 8) so it can take the kid button's overtravel.
    The kid button is an optional rocker disc over the whole back. A press below
    its two top pads tips a nub onto the tab (5.3 N at the centre, 2.4 N at 6
    o'clock), and wings landing on the plate fix the tab's travel however hard it
    is mashed. It twist-locks with four thick teeth (≥ 64 N pull-off), and a latch
    only a coin can lift stops a child twisting it off.
    D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
2026-10-14 Hoop telegraph key: a 2:1 lever on a pin with the badge leaned back 40° (or 50°)
    Two prints of the front-BOOT rocker failed the same way: it is a 1:1 lever on a
    thin flexure, so the key travel was no more than the ~1 mm the nub needs and the
    press went into bending the plastic. This variant is a telegraph key. A lever on a
    Ø3 pin between two posts has a knob at the front; its short rear arm tips up into
    the button plate's BOOT tab, which faces down now that the case leans 40° back.
    The lever is 2:1 (knob arm 23.1, nub arm 12.1), so the knob travels 3.2 mm to the
    click (2.6–3.8 across the gap tolerance) at about 1.75 N, and an anvil under the
    knob stops it at 4.2 mm, so a 30 N press goe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
2026-10-14 Cases: pry notch to get a tight plate off; USB-C slot 2 mm bigger all round
    Aaron's PLA print was so tight he couldn't get the back plate off again. The
    snap stays as tight as it is; instead every USB-only-family case gets a 5 mm pry
    notch through the back rim at 10 o'clock (seen from the front), cut 1 mm under
    the plate's edge so a screwdriver or coin can lever it out.
    The USB-C opening was still too tight for some cables' plastic: it is now cut
    2 mm bigger all round (10.0 x 4.3 -> 14.0 x 8.3, measured in the STL). The plug
    model stays the real shell; a new Feature.grow enlarges only the cut, and 45 deg
    roof corners keep the roof's bridge at 9.2 mm, under BRIDGE_MAX. All 16
    pocketwatch-fam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
2026-10-15 Pendant: USB-C receptacle sticks out past a flat at 12 o'clock
    Cable overmolds kept failing to fit the 14.0 x 8.3 plug slot in the crown
    boss, because the slot sits about 3 mm deep and every cable's overmold is a
    different shape. Instead of chasing the overmold, the case now stops short of
    the port so the overmold seats on the receptacle and touches no plastic.
    One half-plane, y <= tip_y - RAD_CLR - PORT_OUT, bounds every printed part:
    case, both back plates and the kid button. The badge floats RAD_CLR in the
    bore, so a plug pushes the board down that far before it seats; PORT_OUT
    (0.5) is what still stands proud then, and 1.65 at rest. The outline pieces
    are clipped before chamfering so th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
2026-10-15 Pendant docs: USB-C sticks out; log, design entry, archive, handoff
    Aaron asked for the pendant USB-C hole to be 2 mm taller, or better, for the
    port to stick out. The second plug-fit request in a day, so the slot is gone
    rather than grown (previous commit). This logs the request first, records the
    decision and the rejected taller slot in DESIGN.md, archives the four v1 STLs
    he is printing now, and rewrites the pendant README for the flat: new masses,
    the 12 o clock render, and the one new weak point (the bare case is a C at
    12 o clock until the plate snaps in). HANDOFF gets his three-step pendant queue
    and notes the pendant case never got the pry notch. The whiteboard STATUS and
    the stale s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
2026-10-15 Print log: the pendant kid button failed (did not fit); kids case replaces it
2026-10-15 Kids case and a pry notch on the pendant
    The twist-lock kid button did not fit on its first print, so the kids case
    replaces it with two prints: the pendant case without the lock grooves, and a
    back plate whose BOOT button is one flap. The flap is 8 wide, rooted at x +8
    and runs out through the plate edge. A pole under it clicks BOOT at 1.85 N
    pressed at its outer end, then a foot under that end lands on the case step,
    so a hard press loads the case. The switch takes 6.6 N on the stop (11.4 N
    worst). Pressing over the pole or mid-flap has no stop; the build prints
    that as a known weakness.
    The flap is checked bent into the beam model shape, not turned rigidly. A
    rigid turn drives the pole p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
2026-10-15 Docs: kids case and pendant pry notch; design entry, handoff, pendant README
    The pendant README now marks the kid button as failed and points to the kids
    case, adds the pry notch (about 3:30 from the back) and the new check count.
    DESIGN.md records why the kids case is two prints, not the three Aaron sketched
    (an outer piece had nothing to snap into), its known weakness (only the outer
    end is stopped), and why the pry notch moved to 345 deg. It also notes that the
    USB-only notch at 120 deg is 10 o clock seen from the back, not the front.
    HANDOFF gets the updated pendant queue. Whiteboard STATUS and a note beside
    the Kid s case frame are updated.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
2026-10-15 Battery pendant: v2 case with the port sticking out and a BOOT flap in the lid
    A pendant that carries its own 1000 mAh cell. It is v2-sized (52.3 x 23.4):
    v2 bore, plate, chamber and snapped lid. It has the pendants
2026-10-15 Battery pendant: the full message for dc0cdda
    dc0cdda's message was cut off by a shell quoting error. This empty commit
    carries it in full, because history is never rewritten here.
    v2 bore, plate, chamber and snapped lid. It has the pendant's USB-C port
    sticking out at 12 o'clock and the kids case's flap, moved out into the lid.
    The cell is turned 25.9 deg so the BOOT pole passes beside it. The turn is the
    least that keeps the pole's channel MIN_WALL + BAY_CLR off the cell. The cell's
    half-diagonal is the same at any turn, so the case does not grow. A rectangle in
    a round chamber spins freely, so two ribs on the ch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
2026-10-15 The message for 38db9c8: window flat top widens the pendant lip bar; battery docs
    38db9c8 went out with a stale message file ("Cases: pry notch ... USB-C slot
    2 mm bigger all round", the text of 0796ba6). History is never rewritten here,
    so this empty commit carries what 38db9c8 actually did:
    Aaron printed the pendant with the USB-C port sticking out: "that pretty much
    worked", but the bar over the USB-C tab, the only case joining the two sides at
    12 o'clock, was too thin (2.68 at its narrowest). He wanted it longer in the
    face plane, not thicker, and picked growing it down over the screen's black
    border over growing it up past the port (that would have stopped plugs thicker
    than ~9.4). New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
